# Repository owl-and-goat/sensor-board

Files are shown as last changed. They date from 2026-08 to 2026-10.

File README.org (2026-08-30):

#+title: sensor board

* stackup & antenna
see https://jlcpcb.com/impedance; stackup is currently set to 1.6 mm, controlled
impedance, 1 oz copper on all layers, which gives 0.203 mm / 0.008" outer
prepreg thickness for the "no requirement" stackup. board thickness is 1.6 mm ≈
0.062", so we'll be using the first of [[https://www.silabs.com/documents/public/application-notes/an1088-designing-with-pcb-antenna.pdf][these]] reference layouts.

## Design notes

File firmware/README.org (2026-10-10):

#+title: firmware

* build and flash

a board needs two images: the bootloader from =../bootloader=, at the start
of flash, and this firmware after it. the bootloader only swaps in a firmware
update (see below) and starts the firmware. from the top of the repository:

#+begin_src sh
  just flash                  # both, through the st-link on the jtag port
  just update                 # the firmware, over usb, through the running firmware
  just update-all             # the same for every attached board, one after the other
  just push                   # the firmware, to every board on the network, through the attached one
  just dfu-flash              # both, over usb, through the rom bootloader
  just dfu-flash-all          # the same for every attached board, one after the other
#+end_src

with several boards attached, =just update=, =just push= and =just dfu-flash=
take =--board <serial>=. to flash only the firmware through the probe and
watch the board's log (the bootloader has to be on the board already):

#+begin_src sh
  cargo run --release         # flash, reset, stay attached (ctrl-c to leave)
#+end_src

** firmware updates

=just update= runs =sensor-board-cli firmware update <image>= with the image
that =just firmware-image= builds. the board writes the image to its staging
area in flash, verifies it, and restarts. its bootloader then swaps the two
firmwares, which takes about ten seconds. the new firmware first runs on
trial. once the board is back on its network (or has no network to join),
the update is confirmed. if the board restarts before that, or is not back
within five minutes, the bootloader restores the old firmware. =firmware
status= shows which build is running and the state of the update.

=just push= runs =firmware push <image>=, which updates every board on the
network without plugging any of them in. the attached board receives the
image over usb and offers it to the others every ten seconds. a board that
runs another build fetches the image from the attached board in small
chunks, verifies it, and restarts into it in the same way, including the
trial. the command follows the boards' reports, which show the build each
board runs. it updates the attached board last, once every board it has
heard from runs the image. a board whose trial of a build failed does not
fetch that build again.

during a push, the command shows a summary line with the number of boards
that run the image, and below it a progress bar for each board that is
fetching. the bars are based on the chunks that the boards request from the
attached board:

#+begin_example
  ⠙ 1 of 3 other boards run build 1791154812 (2m)
  4B0041000350475532303120 ███████████████░░░░░░░░░░░░░  56%    1.85 KiB/s  eta 48s
  a board                  ███░░░░░░░░░░░░░░░░░░░░░░░░░  12%    1.71 KiB/s  eta  2m
  4D0021000350475532303120 ████████████████████████████ 100%  restarting
#+end_example

a bar shows the board's serial number once the board has sent its id.
firmware from before 2026-10-04 does not send it, so such a board is shown
as "a board". a board that has the whole image keeps its bar for half a
minute while it verifies the image, restarts and swaps, and is listed as
=updated= at its next report. the bars are only drawn on a terminal (and not
if =TERM= is =dumb=), and only if the attached board's firmware can report
progress (run =just update= first if it cannot).

all boards fetch at the same time, even when they relay for each other (see
=TODO.org=). a board can only be updated this way once it runs a firmware
that supports it, so its first such firmware has to come over usb.

a board stays on its network through all of this: its stored configuration
is in a separate page that neither firmware slot covers.

** without the firmware: usb dfu

=just dfu-flash= asks the running firmware to enter the rom bootloader and
then runs the command below. the command also works on a board that entered
the rom bootloader another way (see "getting into the bootloader"). with
several boards in the rom bootloader, select one with =dfu-util -p <usb
path>= (=lsusb -t= shows the paths).

#+begin_src sh
  dfu-util -d 0483:df11 -a 0 -s 0x08000000:leave -D target/sensor-board-flash.bin
#+end_src

the image is the bootloader, padded with blank flash up to 0x08007000,
followed by the firmware (=just firmware-image=, then the bootloader's part
of =_flash-image= in the =Justfile=).

* talking to a board: sensor-board-cli

the firmware is a usb device with one vendor interface, which carries
[[https://github.com/jamesmunns/postcard-rpc][postcard-rpc]] messages. =../protocol= defines the endpoints and all their
types. the firmware serves them (=src/rpc.rs=) and =../cli= calls them. a
board's usb serial number is its chip's unique id, and =--board= takes any
unambiguous prefix of it.

#+begin_src sh
  cd ../cli
  cargo run -- list                        # every board: firmware build, network status
  cargo run -- network init                # put all attached boards on one thread network
  cargo run -- network dataset --board 4b  # that network's dataset, hex (holds the network key)
  cargo run -- network neighbors --board 4b  # that board's direct neighbors and their link quality
  cargo run -- network routers --board 4b  # every router, and the board's route to it
  cargo run -- network leave --board 4d
  cargo run -- coprocessor status --board 4d           # what cpu2 has installed and is running
  cargo run -- coprocessor install <image> --board 4d  # see "a new board" below
  cargo run -- coprocessor uninstall --board 4d        # remove the wireless stack
  cargo run -- bootloader --board 4d       # reboot into the rom bootloader
  cargo run -- firmware status --board 4d  # the running build, and the state of an update
  cargo run -- firmware update <image> --board 4d  # see "firmware updates" above
  cargo run -- firmware push <image> --board 4d    # update every board on the network
  cargo run -- network addresses --board 4b  # that board's ipv6 addresses
  cargo run -- network show                # every sensor board on the network; see below
  cargo run -- reports watch               # print the boards' sensor reports as they arrive
  cargo run -- metrics show --board 4d     # the board's current prometheus metrics
  cargo run -- config show --board 4d      # the board's configuration
  cargo run -- config set --board 4d --sensor temperature=30s  # see "board configuration" below
#+end_src

=network init= puts every attached board on one network. the boards join one
at a time, and the command waits for each to attach. it chooses the network
in this order: the one saved by an earlier run, in
=~/.local/state/sensor-board/dataset= (=--dataset-path= selects another
file); if nothing is saved, the network of the first board that has one;
otherwise a new network (random key, pan id and channel). the chosen network
is saved, so that a board plugged in on its own later joins the same one.
=--force-reinit= always creates a new network and moves the attached boards
to it. the saved file contains the network key.

the host creates the dataset, and a board is only ever told to join one. a
board keeps its dataset in flash and rejoins at every power-up, until
=network leave=.

** the boards on a network

=network show= lists the sensor boards on a thread network: serial number,
rloc16, ipv6 address, and the link to each board.

#+begin_src sh
  cargo run -- network show                    # through an attached board, or else the border router
  cargo run -- network show --board 4c         # through that attached board
  cargo run -- network show --border-router    # through the border router at cerberus:8081
  cargo run -- network show --border-router otbr.lan:8081
#+end_src

through an attached board, that board multicasts a discovery request, and
every board that receives it replies with its serial number, rloc16 and
addresses. through a border router, the cli reads the list of devices from
the border router's rest api and sends the request to each device's routable
address itself, from udp port 61623. this machine needs a route to the thread
network for that.

- a board is listed only if its firmware has discovery. boards on an older
  firmware and other thread devices do not reply.
- the address is the board's routable address if it has one, and its
  mesh-local address otherwise.
- age, quality and avg rssi describe the link between each board and the
  device that was asked: the attached board, or the border router. they show
  as =-= for a board that has no direct radio link with that device, and for
  the attached board itself. the attached board's parent also shows =-=
  while the attached board is a child, as in =network neighbors=.
- the border router's api has no age or rssi, and it has the quality only for
  boards that are routers.

tested on 2026-10-10 with one board on a firmware that has discovery: through
that board, which lists itself, and through the border router, with the
quality once the board was a router. not tested: a second board's reply
arriving through the attached board, and the link columns filled from the
attached board's neighbor table.

** sensor reports

every board multicasts a report with its sensor readings to its network
every ten seconds. =reports watch= prints the reports that one attached
board receives, including that board's own, for as long as the command runs.
the board has to stay attached: if it goes away (unplugged, reflashed), the
command waits for it to come back. any board can do this. a board only
understands reports from firmware with the same report layout, and ignores
the rest. =firmware push= also uses these reports, to learn which build each
board runs.

** metrics

a board exports its metrics to prometheus itself, over its thread network
and a border router. how it exports them depends on the power mode in its
configuration (see below):

- =aux=: the board serves a scrape endpoint at =/metrics= on tcp port 9469.
  it handles one scrape at a time.
- =battery=: the board pushes to the pushgateway in its configuration after
  every sensor read, as job =sensor_board= with its serial number as the
  instance. after a failed push it waits a minute before the next one.

a board without a configuration does neither.

the metrics are the readings of the sensors enabled in the configuration,
each read at its own interval, plus counters for scrapes and pushes. every
metric has a =board= label with the board's serial number. =metrics show=
prints the current metrics over usb.

to scrape a board, prometheus needs an address that is reachable from
outside the thread network. =network addresses= lists it as =routable=. a
board gets one once a border router advertises a prefix.

#+begin_src yaml
  scrape_configs:
    - job_name: sensor-board
      static_configs:
        - targets: ["[fd12:3456:789a:1:4c51:2d3d:c69c:4af6]:9469"]
#+end_src

a pushgateway is set as an ipv6 address and a port. the border router has to
be able to route from the board to that address:

#+begin_src sh
  cargo run -- config set --power-mode battery --pushgateway '[fd12:3456::1]:9091'
#+end_src

tested on a board on 2026-10-10: metrics over usb, switching between the two
modes when the configuration changes, pushes to addresses where nothing
answers, and a scrape with =curl= from a machine on the lan, through a
border router. not tested yet: a push that succeeds.

** board configuration

a board stores a configuration in flash, next to its network's dataset. it
holds the board's number, its power mode, and for each sensor either a poll
interval or that the sensor is off. =config show= prints it. =config set=
changes the settings it is given and keeps the rest. the power mode also
selects how the board exports its metrics (see "metrics" above):

#+begin_src sh
  cargo run -- config set --id 3 --power-mode aux    # a board's first configuration needs these two
  cargo run -- config set --sensor temperature=30s --sensor color=off
  cargo run -- config show
#+end_src

with =--remote <serial>=, both commands apply to a board that is not
attached. the attached board asks it over their network, and gives up after
six seconds. =--remote= takes the board's full serial number, as =reports
watch= prints it.

#+begin_src sh
  cargo run -- config set --remote 4D0021000350475532303120 --sensor temperature=30s
#+end_src

a firmware that changes the layout of the configuration (by adding a sensor,
for example) cannot read a configuration that the previous firmware stored.
the board then has no configuration until it is set again. two boards whose
firmwares have different layouts do not answer each other's requests either.

so far only the metrics use the configuration: the power mode, the
pushgateway, and the intervals of the sensors that have a driver. the
board's number is not used yet. sensor reports are sent every ten seconds
regardless, and a board on battery is still a full router.

* getting into the bootloader

only needed for dfu; probe-rs does not need it. any of these puts the chip in
usb dfu mode (=lsusb= shows =0483:df11=):

- short the two pads of jp1 (boot0) while plugging in usb. this is hardware
  only, so it works whatever is in flash. take the coin cell out first: vbus
  and the cell share a net.
- =sensor-board-cli bootloader=, while the firmware is running.
- three boots in a row that end in a panic, a hard fault or a watchdog reset.
  a single failure only restarts the firmware.

* cpu2: fus, the thread stack, and openthread

cpu2 (the cortex-m0+ radio core) runs st's signed firmware: fus (the
firmware upgrade service) and, once installed, the thread ftd stack.

** a new board

a new chip is blank, with an old fus and no wireless stack. from the top of
the repository, with only the new board on usb:

#+begin_src sh
  just new-board          # bootloader and firmware over dfu, then fus and the thread stack; under a minute
  just cli network init   # join the network saved by an earlier run
#+end_src

=just new-board= fetches st's two images, verifies them against known hashes,
and then runs these commands:

#+begin_src sh
  dfu-util -d 0483:df11 -a 0 -s 0x08000000:leave -D sensor-board-flash.bin
  sensor-board-cli coprocessor install stm32wb5x_FUS_fw.bin          # fus 1.2.0 -> 2.2.0, a few seconds
  sensor-board-cli coprocessor install stm32wb5x_Thread_FTD_fw.bin   # about half a minute
#+end_src

without =--board=, =coprocessor install= selects the only attached board
whose coprocessor is running fus, which is the new one. it reads the kind
and version from the image, and skips a board that already has that version.

fus can only install while fus itself is running, so a board that has a
stack needs =coprocessor uninstall= first.

the third and fourth boards were set up this way on 2026-10-04. the first
two got their stacks in september from the text console of the bring-up
firmware (commit 9caa670).

** result (2026-09-16, two boards side by side on one hub)

a leader (rloc16 0xd400) and b child (0xd401) on channel 14, pan 0x5f11.
ping a to b 5/5 with 21 to 69 ms rtt, b to a 5/5 with 21 to 23 ms. a's
neighbor table: b at rssi -18 dbm, link margin 82 db, lqi 3. antenna,
balun and stack all work; range and tx power are untested.

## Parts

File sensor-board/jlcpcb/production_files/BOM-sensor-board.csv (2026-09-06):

Comment | Designator | Footprint | LCSC | Quantity
0.1uF | C12,C15,C16,C17,C18,C2,C21,C22,C23,C30,C31,C4,C6,C7,C9 | C_0402_1005Metric | C141382 | 15
100K | R17 | R_0402_1005Metric | C25741 | 1
100pF | C10 | C_0402_1005Metric | C1546 | 1
10k | R2,R3,R6,R7,R8,R9 | R_0402_1005Metric | C25744 | 6
10nH | L1 | L_0402_1005Metric | C3911026 | 1
10uH | L2 | L_0805_2012Metric | C162582 | 1
18 uH | L3,L4,L5,L6 | L_0603_1608Metric | C275349 | 4
1M | R13,R14 | R_0402_1005Metric | C26083 | 2
1N4148WS | D2 | D_SOD-323 | C2128 | 1
1k | R1,R10,R11,R12,R15,R16,R19,R20,R21 | R_0402_1005Metric | C11702 | 9
1uF | C24,C32,C8 | C_0402_1005Metric | C52923 | 3
2.2M | R18 | R_0603_1608Metric | C22938 | 1
32.768KHz | Y2 | Crystal_SMD_3215-2Pin_3.2x1.5mm | C94673 | 1
32MHz | Y1 | Crystal_SMD_2016-4Pin_2.0x1.6mm | C5441424 | 1
33 pF | C25,C26,C27,C28 | C_0402_1005Metric | C1562 | 4
4.7uF | C11 | C_0805_2012Metric | C1779 | 1
4.7uF | C1,C13,C14,C19,C20,C29 | C_0402_1005Metric | C23733 | 6
5.1k | R4,R5 | R_0402_1005Metric | C25905 | 2
6.2pF | C3,C5 | C_0402_1005Metric | C82154 | 2
LED | D1 | LED_0805_2012Metric | C84256 | 1
MCP1703Ax-300xxTT | U3 | SOT-23 | C625372 | 1
MLPF-WB55-01E3 | U1 | MLPF-WB55-01E3_STM | C2651048 | 1
STM32WB55CCUx | U2 | QFN-48-1EP_7x7mm_P0.5mm_EP5.6x5.6mm | C404023 | 1
SW_Push | SW1 | SW_SPST_TS-1088-xR020 | C720477 | 1
Si2312 | Q1,Q2 | SOT-23 | C142518 | 2
USB_C_Receptacle_USB2.0_16P | J1 | USB_C_Receptacle_G-Switch_GT-USB-7010ASV | C2988369 | 1

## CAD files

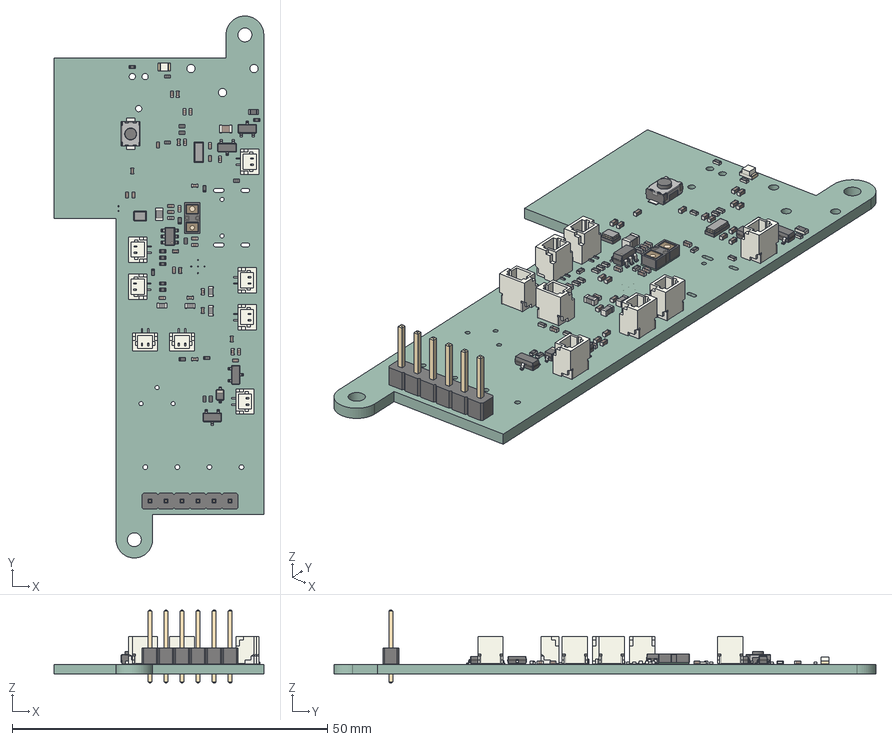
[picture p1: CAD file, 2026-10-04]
sensor-board/sensor-board.step
33.2 x 85.9 x 11.5 mm
C_0402_1005Metric x 31
D_SOD-323
R_0402_1005Metric x 20
SOT-23 x 4
Crystal_SMD_3215-2Pin_3.2x1.5mm
SOT-23-6
JST_SH_BM02B-SRSS-TB_1x02-1MP_P1.00mm_Vertical x 8
L_0805_2012Metric
L_0603_1608Metric x 4
Crystal_SMD_2016-4Pin_2.0x1.6mm
LED_0805_2012Metric
ST_VL53L1x
C_0805_2012Metric
PinHeader_1x06_P254mm_Vertical
R_0603_1608Metric
L_0402_1005Metric
SW_SPST_TS-1088-xR020
sensor-board_PCB

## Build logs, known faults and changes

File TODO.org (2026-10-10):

#+title: sensor board todo
#+todo: TODO(t) | DONE(d) WONTFIX(w)

* Layout fixes
** Grounding (fix before fab)                                                                                            :ground:
*** DONE [#A] Add a via array to the MCU (U2) exposed pad
CLOSED: [2026-09-02 Wed 22:45]
Pin 49 is VSS and the RF ground return. It currently reaches ground through
a single 0.4 mm F.Cu trace from the pad centre (174.49, 54.49) to the via at
pin 22. Put 9-16 GND vias in the pad at 0.8-1.0 mm pitch.
*** DONE [#A] Add GND vias at the balun/filter (U1) ground pads A2, B1, B2, B3
CLOSED: [2026-09-03 Thu 21:54]
Nearest GND via is 1.6-2.6 mm away (the pin-22 VSSRF via at 171.06, 56.24),
shared with the VDDRF decoupling. ~2 mm of trace is ~25 ohm at 2.4 GHz. One
via per pad, directly at or under the pad.
*** DONE [#A] Add GND vias at the VDDRF decoupling caps C9 and C10 ground pads
CLOSED: [2026-09-03 Thu 22:53]
Pads at (168.85, 56.90) and (169.87, 56.90); they currently return via the
same F.Cu GND trace to the pin-22 via.
*** DONE [#A] Give every GND pad its own via
CLOSED: [2026-09-03 Thu 22:11]
Only 8 of 81 SMD GND pads are within 1 mm of a GND via; 25 are >3 mm away;
158 mm of GND is routed as F.Cu traces. Worst cases:
- [X] U9 (FDC2114) GND pins 3, 4 and thermal pad 17: 3.9-4.3 mm
- [X] U5 (VL53L1X) GND pins 2, 3, 4, 6, 12: 2.4-4.1 mm
- [X] C17, C20 (VL53L1X decoupling): 3.8 / 4.3 mm
- [X] C15: 4.3 mm
- [X] U2 pin 32 VSSSMPS: 2.8 mm
- [X] C1, C14, C6 (SMPS caps): 2.0-2.6 mm
- [X] C12: 3.1 mm; C23: 2.5 mm
- [X] U11 (DRV5032) GND: 5.9 mm
- [X] MIC1 GND pads: 1.9-3.9 mm
- [X] U8 (LIS2DE12) GND pads: 3.2-3.7 mm
- [X] U6 (TLV4082) GND: 2.4 mm
- [X] J1 (USB-C) shell/GND pads: 5-7 mm
*** DONE [#A] Add GND pours on F.Cu and B.Cu with stitching vias
CLOSED: [2026-09-03 Thu 22:20]
Exclude the antenna area (everything left of x = 167.1 for y < 61.06). Keep a
generous clearance from the FDC2114 tank/electrode traces. Stitch to In1 at
<= 2 mm spacing in the RF section (AN5165).

** Signals routed on plane layers (fix before fab)                                                                       :planes:
*** WONTFIX [#A] Move VLXSMPS (SMPS switch node) off In1
CLOSED: [2026-09-03 Thu 22:22]
2.1 mm slot at x = 175.77, y 58.42-60.52, directly under C1 and C14. Re-place
L1 and/or C1/C14 so pin 33 -> L1 is a short, direct F.Cu trace.
*** WONTFIX [#A] Move SCL and SDA off In1
CLOSED: [2026-09-03 Thu 22:22]
Two ~6 mm diagonal slots under the MCU south-east quadrant:
scl (175.26, 54.84) -> (179.68, 59.26); sda (174.74, 55.87) -> (179.07, 60.20).
Crossed by usb_d+/usb_d-, sai1_d1, dist_int, dist_shut and the SMPS GND traces.
*** WONTFIX [#A] Move water1 and water2 off In2
CLOSED: [2026-09-03 Thu 22:23]
13 mm and 12 mm on the +3V0 plane; together they wall off a 3V0 island under
the MCU that is only fed through the F.Cu decoupling vias.
*** WONTFIX [#A] Move hp1 and hp3 off In2
CLOSED: [2026-09-03 Thu 22:23]
hp1 slot (168.0, 57.23) -> (170.3, 54.2) passes directly under the balun U1.
*** DONE [#B] Remove the stray GND track segments on In2 near (169.3-169.5, 57.8-59.05)
CLOSED: [2026-09-03 Thu 22:26]

** Crystals                                                                                                             :crystal:
*** DONE Local ground islands under Y1 and Y2 (AN2867 structure) - keep as is
CORRECTION to the first review pass, which wrongly said there was no copper
under the crystals. What is actually there: a filled GND =gr_rect= on In1
under each crystal, isolated from the main In1 plane by the keepout gap, a
GND guard ring of graphic lines on F.Cu, a via ring tying the top ring to the
island, and a single-point tie to the rest of ground:
- Y1: via (169.3, 59.05) -> In2 stub -> via (169.5, 58.47) -> main In1 plane
  and B.Cu track to the U2 pin 22 (VSSRF) via.
- Y2: via (178.9, 48.4) -> B.Cu track -> via (179.0, 47.5) -> main In1 plane.
Only crystal-related grounds (Y1.2, C3.2, C5.2) land on the islands. The
keepouts are what create the isolation gap; do not delete them.
*** DONE [#B] Connect Y1 pad 4 to the guard ring / island
CLOSED: [2026-09-03 Thu 22:28]
Pad 4 (171.6, 61.25) has no net; only one of the two case-ground pads is
grounded. Needs a schematic change.
*** WONTFIX [#B] Separate the LSE traces
CLOSED: [2026-09-03 Thu 22:30]
lf_osc+ and lf_osc- run side by side for 2.2 mm at 0.24 mm gap (y = 49.97 and
50.42, x 176.9-179.1), outside the ring. Put a GND trace between them or
spread them.
*** WONTFIX [#B] Move the +3V0 traces to C2/C7 away from the LSE traces
CLOSED: [2026-09-03 Thu 22:30]
+3V0 at (177.04-178.05, 49.47) and (177.24-178.31, 51.05) run 0.2 mm from the
LSE traces where they leave the ring.
*** DONE [#C] Relax the via ring pitch to a DRC-legal hole-to-hole spacing
CLOSED: [2026-09-03 Thu 22:30]
Currently 0.38 mm; this is the source of most hole_to_hole warnings. 0.6-1.0
mm pitch loses nothing for a guard ring.
*** DONE [#C] Consider landing the Y2 island tie at an MCU VSS pin
CLOSED: [2026-09-03 Thu 22:33]
AN2867 wants the local ground tied to the nearest MCU ground pin; the Y2 tie
currently lands on the main plane at (179.0, 47.5). Y1's tie already reaches
pin 22. Low priority once the U2 exposed pad has its via array.
*** WONTFIX [#C] Move C3/C5 (LSE load caps) between the crystal and the MCU
CLOSED: [2026-09-03 Thu 22:33]
They are on the far side of Y2 at x = 182.0, inside the ring. Optional;
would need the ring reshaped.
*** Note: no In2 (+3V0) copper under either island
Y2 by the 4-layer keepout, Y1 because the ring via antipads island the In2
fill and it is removed. Harmless for the crystals (the In1 island shields
them); it just leaves a ~4x4 mm hole in the 3V0 plane. No action.

** Antenna / RF                                                                                                              :rf:
*** DONE [#B] Reroute color_int away from the antenna base
CLOSED: [2026-09-03 Thu 22:33]
F.Cu at x = 168.06 from y 56.56 to 60.50, between the feed pad and the
shorting-arm pads; its via at (168.2, 56.5) is 0.45 mm below the 50 ohm feed.
Take it up on B.Cu from U2 pin 19 instead.
*** DONE [#B] Make In2 GND (not +3V0) in the antenna base / RF section
CLOSED: [2026-09-03 Thu 22:36]
AN1088 wants ground on layers 2 and 4 next to the antenna. Cut the 3V0 plane
back from the antenna base and RF section, fill with GND, stitch to In1.
*** DONE [#C] Check the coin cell (BT1) body clearance from the antenna arm
CLOSED: [2026-09-03 Thu 22:37]
Holder pads at (183.98, 37.34) near the top edge; the arm runs x ~ 158.7,
y 40.7-60.6. Any large metal within ~5-10 mm of the arm will detune it.
*** WONTFIX [#C] Convert the antenna radiator polygon into pad 2
CLOSED: [2026-09-03 Thu 22:37]
Still a netless F.Cu graphic; produces the shorting_items DRC error against
pad 2 (GND). Fine as fabricated, but the pad form removes the error.
*** DONE 50 ohm feed: 0.37 mm on 0.203 mm prepreg computes to ~51 ohm; OK
*** DONE Shorting arm has two THT GND pads at the base; OK
*** DONE No copper on any layer under the antenna; plane edge at the base; OK

** SMPS                                                                                                                    :smps:
*** WONTFIX [#B] Tighten the SMPS loop after moving VLX back to F.Cu
CLOSED: [2026-09-03 Thu 22:37]
L2 is 3 mm from Y1. Keep VLX short, keep C1/C14 GND on their own vias, give
pin 32 (VSSSMPS) its own via.

** Sensor and analog nets                                                                                                :sensor:
*** DONE [#B] Separate the FDC2114 channel 3 B trace from the channel 2 electrode net
CLOSED: [2026-09-03 Thu 22:50]
IN3B runs ~10 mm on B.Cu at the 0.1 mm minimum gap from Net-(J10-Pin_1)
(channel 2 electrode). Channel-to-channel crosstalk on the most sensitive node.
*** DONE [#B] Separate the channel 3 electrode net from SCL
CLOSED: [2026-09-03 Thu 22:50]
Net-(J11-Pin_1) runs 1.9 mm at 0.1 mm gap from scl on B.Cu.
*** DONE [#B] Bundle each FDC channel's A/B pair together, away from other channels and I2C
CLOSED: [2026-09-03 Thu 22:51]
*** DONE [#C] Shorten / match the FDC sensor trace lengths
CLOSED: [2026-09-03 Thu 22:51]
Per-channel totals: ch0 ~16 mm, ch1 ~18 mm, ch2 ~23 mm, ch3 ~33 mm. TI:
short traces, matched if matched channel response is needed.
*** WONTFIX [#B] Move the relay GPIO trace away from the comparator input U6 IN2
CLOSED: [2026-09-03 Thu 22:52]
relay on B.Cu runs at x = 173.18 and x = 173.78 on both sides of the 1 Mohm
U6-IN2 node at x = 173.48 (y 65-67.7), 0.3 mm pitch; hp4 also runs 3.5 mm
alongside it on F.Cu. Relay edges will fire false water events.
*** WONTFIX [#C] Reroute motion (B.Cu, x = 175.25) so it does not run over the water2 slot
CLOSED: [2026-09-03 Thu 22:52]
Moot once water2 leaves In2.

** Board / DRC housekeeping                                                                                                 :drc:
*** DONE [#A] Close the board outline
CLOSED: [2026-09-03 Thu 22:37]
Top-right corner: top edge ends at (190.50, 35.66), right edge starts at
(190.53, 35.69). JLCPCB will query an open outline.
*** DONE [#C] Fix the vendor footprint courtyards (U1, MIC1, U8) so DRC is readable
CLOSED: [2026-09-03 Thu 22:37]
*** DONE [#C] Clean up the co-located / too-close vias flagged by hole_to_hole
CLOSED: [2026-09-03 Thu 22:37]
Mostly the Y1 ring; also water1/water2, hp2/hp3, sda/scl, JP1 pairs.

* Firmware
** TODO Update boards over the mesh in an order that keeps the network together
=firmware push= makes every board fetch the update at once, as soon as it
receives the offer. A board is off the network for about half a minute, while
its bootloader swaps the images and until it has rejoined. A router that is
off the network does not relay, so a board behind it loses its connection to
the board it was fetching from, and has to wait for the next offer to
continue. Instead, update the leaf boards first (those that no other board
is reached through), then work inwards to the board on USB, which is updated
last. Update one board at a time, and wait for each to report its new build
before starting the next.

With five boards, every board is a router, so leaves cannot be identified by
role. The order has to come from the gateway's router table (=network
routers=): update the board with the highest path cost first, and never
update a board that is the next hop to a board that is still waiting.
* Rev. 2
** TODO fix the pin numbering for the color sensor footprint
half of them are the wrong way gdi

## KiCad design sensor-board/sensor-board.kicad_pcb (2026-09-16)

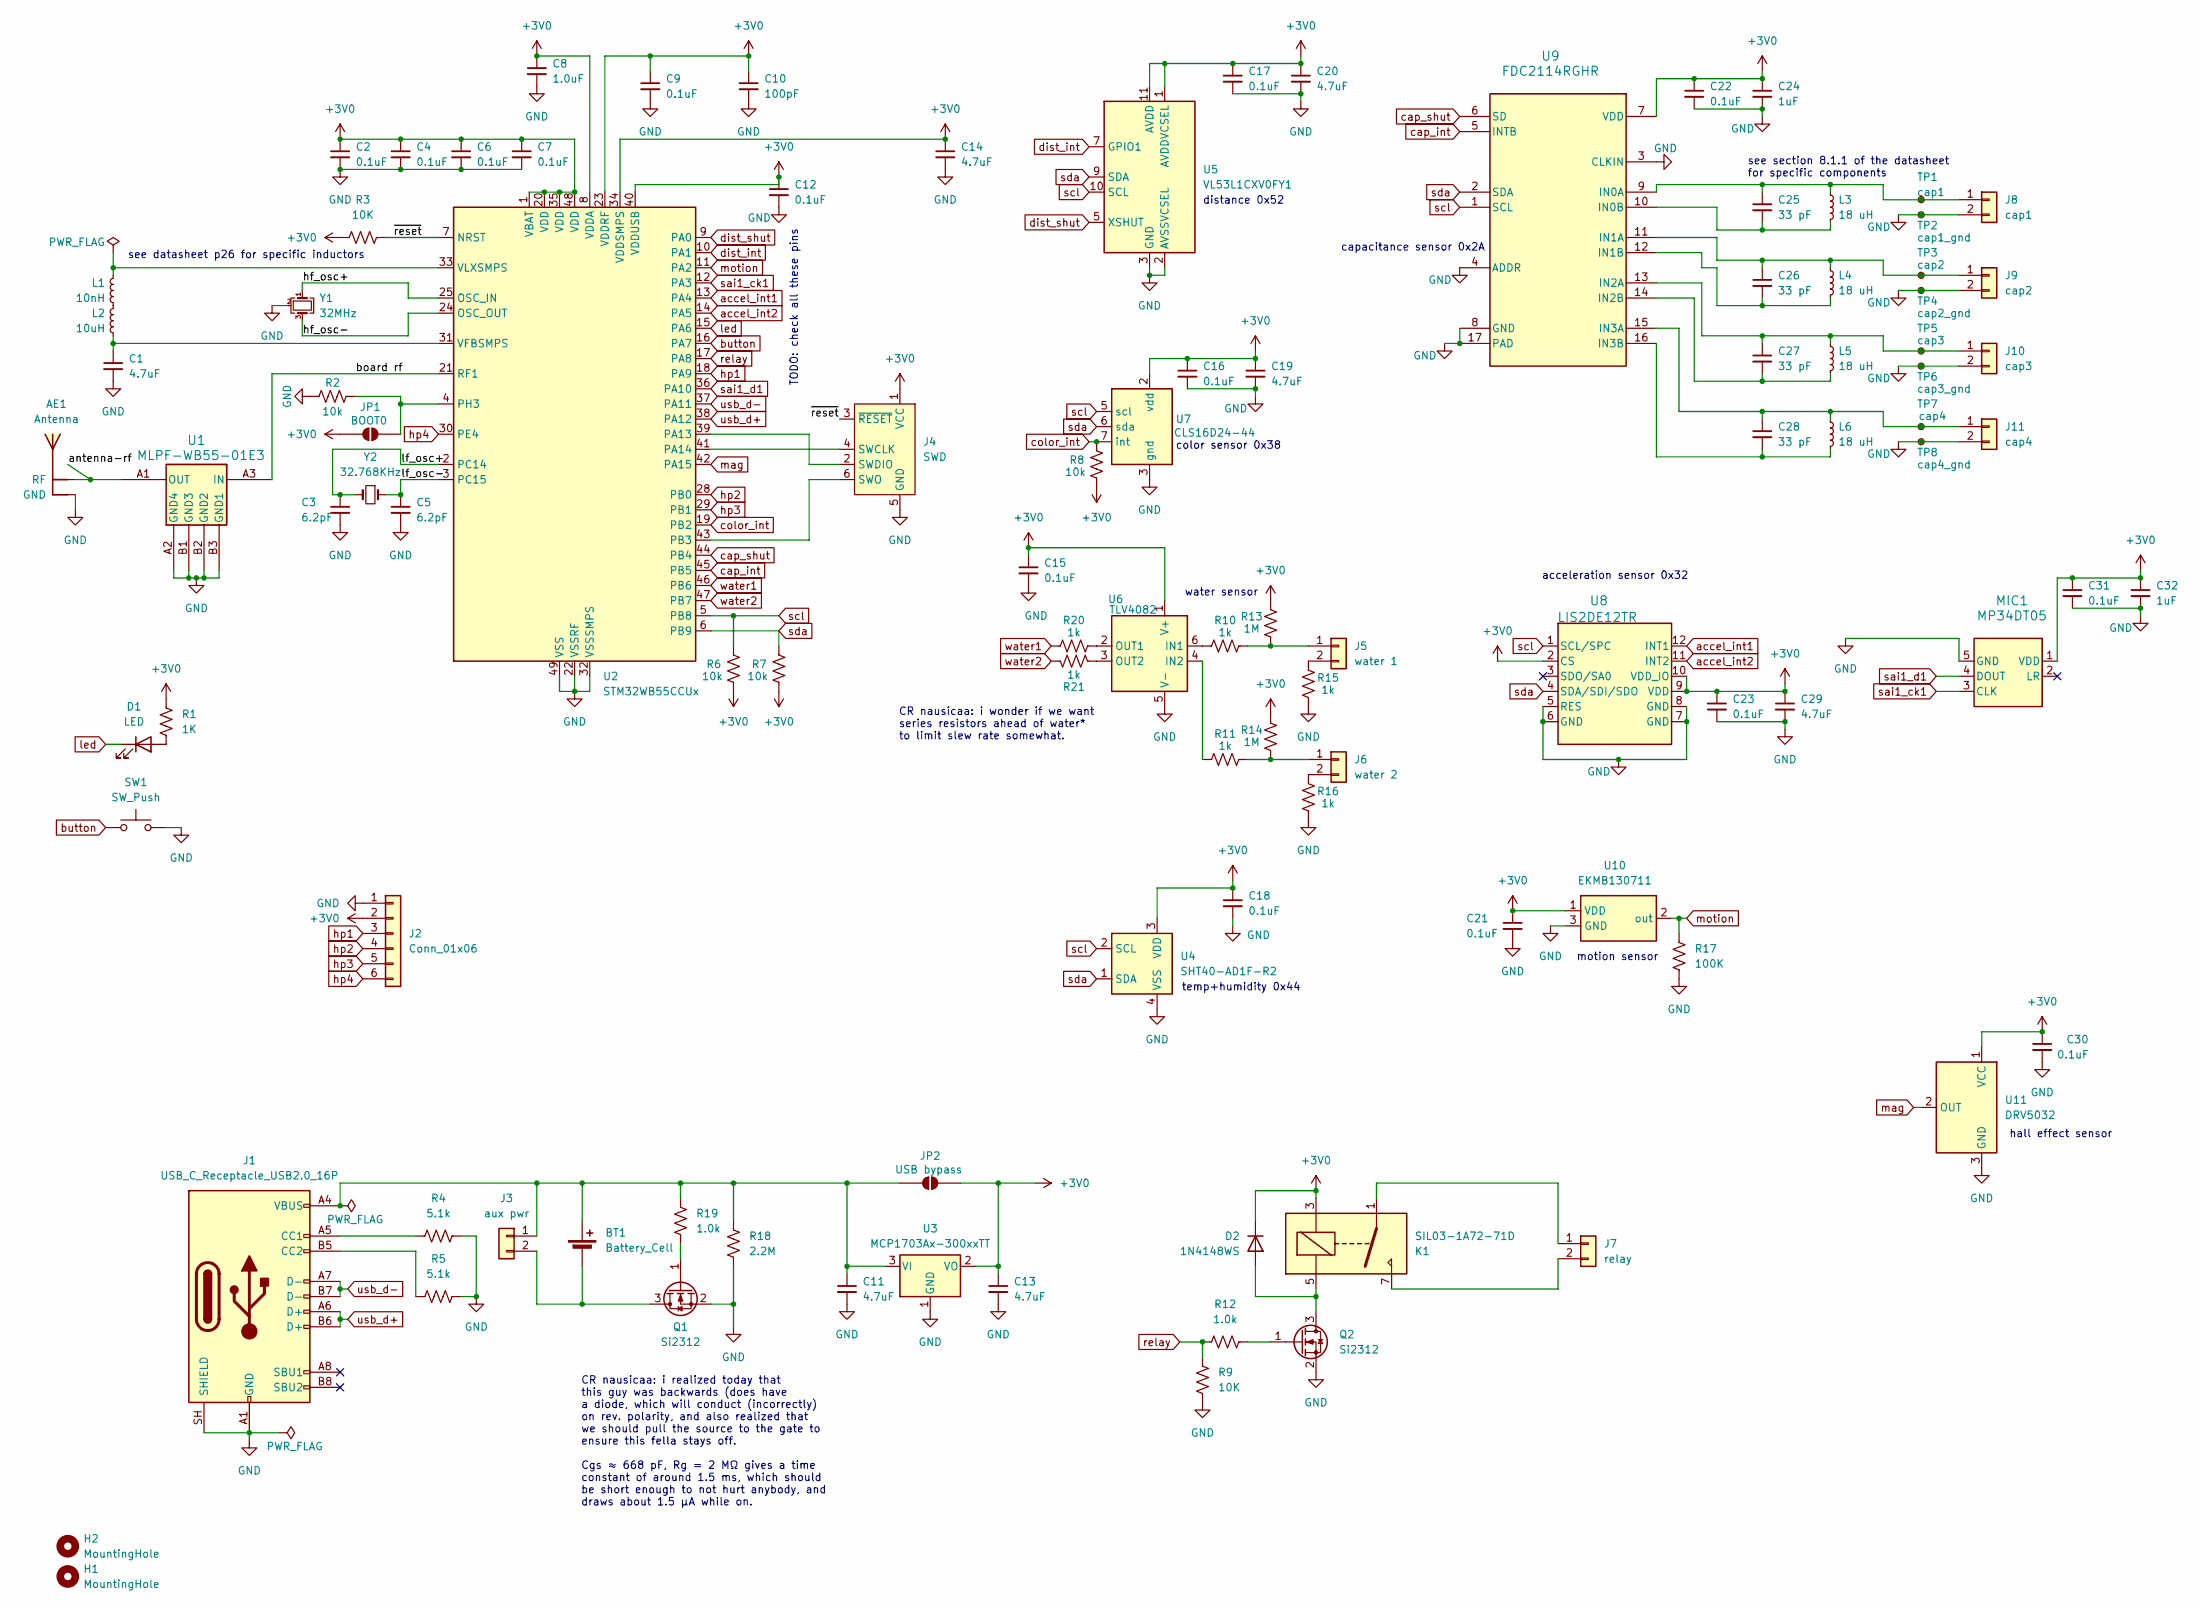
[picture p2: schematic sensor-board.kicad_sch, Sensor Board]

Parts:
AE1: Antenna; Antenna_2.4GHz_InvertedF_SiLabs
BT1: Battery_Cell; BatteryHolder_CR2032
C1, C13, C14, C19, C20, C29: 4.7uF; C_0402_1005Metric; LCSC C23733
C2, C4, C6, C7, C9, C12, C15, C16, C17, C18, C21, C22, C23, C30, C31: 0.1uF; C_0402_1005Metric; LCSC C141382
C3, C5: 6.2pF; C_0402_1005Metric
C8: 1.0uF; C_0402_1005Metric; LCSC C52923
C10: 100pF; C_0402_1005Metric; LCSC C1546
C11: 4.7uF; C_0805_2012Metric; LCSC C23733
C24, C32: 1uF; C_0402_1005Metric; LCSC C52923
C25, C26, C27, C28: 33 pF; C_0402_1005Metric; LCSC C1562
D1: LED; LED_0805_2012Metric; LCSC C84256
D2: 1N4148WS; D_SOD-323; LCSC C2128
H1, H2: MountingHole; MountingHole_2.2mm_M2
J1: USB_C_Receptacle_USB2.0_16P; USB_C_Receptacle_G-Switch_GT-USB-7010ASV
J2: Conn_01x06; PinHeader_1x06_P2.54mm_Vertical
J3: aux pwr; JST_SH_BM02B-SRSS-TB_1x02-1MP_P1.00mm_Vertical
J4: SWD; Tag-Connect_TC2030-IDC-NL_2x03_P1.27mm_Vertical
J5: water 1; JST_SH_BM02B-SRSS-TB_1x02-1MP_P1.00mm_Vertical
J6: water 2; JST_SH_BM02B-SRSS-TB_1x02-1MP_P1.00mm_Vertical
J7: relay; JST_SH_BM02B-SRSS-TB_1x02-1MP_P1.00mm_Vertical
J8: cap1; JST_SH_BM02B-SRSS-TB_1x02-1MP_P1.00mm_Vertical
J9: cap2; JST_SH_BM02B-SRSS-TB_1x02-1MP_P1.00mm_Vertical
J10: cap3; JST_SH_BM02B-SRSS-TB_1x02-1MP_P1.00mm_Vertical
J11: cap4; JST_SH_BM02B-SRSS-TB_1x02-1MP_P1.00mm_Vertical
JP1: BOOT0; SolderJumper-2_P1.3mm_Open_RoundedPad1.0x1.5mm
JP2: USB bypass; SolderJumper-2_P1.3mm_Open_RoundedPad1.0x1.5mm
K1: SIL03-1A72-71D; SIL031A7271D
L1: 10nH; L_0402_1005Metric
L2: 10uH; L_0805_2012Metric
L3, L4, L5, L6: 18 uH; L_0603_1608Metric
MIC1: MP34DT05; HCLGA4_MP34_STM
Q1, Q2: Si2312; SOT-23
R1: 1K; R_0402_1005Metric; LCSC C11702
R2, R6, R7, R8: 10k; R_0402_1005Metric; LCSC C25744
R3, R9: 10K; R_0402_1005Metric; LCSC C25744
R4, R5: 5.1k; R_0402_1005Metric; LCSC C25905
R10, R11, R15, R16, R20, R21: 1k; R_0402_1005Metric; LCSC C11702
R12, R19: 1.0k; R_0402_1005Metric; LCSC C11702
R13, R14: 1M; R_0402_1005Metric; LCSC C26083
R17: 100K; R_0402_1005Metric; LCSC C25741
R18: 2.2M; R_0603_1608Metric; LCSC C22938
SW1: SW_Push; SW_SPST_TS-1088-xR020; LCSC C720477
TP1: cap1; TestPoint_Pad_1.0x1.0mm
TP2: cap1_gnd; TestPoint_Pad_1.0x1.0mm
TP3: cap2; TestPoint_Pad_1.0x1.0mm
TP4: cap2_gnd; TestPoint_Pad_1.0x1.0mm
TP5: cap3; TestPoint_Pad_1.0x1.0mm
TP6: cap3_gnd; TestPoint_Pad_1.0x1.0mm
TP7: cap4; TestPoint_Pad_1.0x1.0mm
TP8: cap4_gnd; TestPoint_Pad_1.0x1.0mm
U1: MLPF-WB55-01E3; MLPF-WB55-01E3_STM; LCSC C2651048
U2: STM32WB55CCUx; QFN-48-1EP_7x7mm_P0.5mm_EP5.6x5.6mm; LCSC C404023
U3: MCP1703Ax-300xxTT; SOT-23; LCSC C625372
U4: SHT40-AD1F-R2; Sensirion_DFN-4_1.5x1.5mm_P0.8mm_SHT4x_NoCentralPad
U5: VL53L1CXV0FY1; ST_VL53L1x
U6: TLV4082; SOT-23-6
U7: CLS16D24-44; CLS-16D24-44-DF8TR8
U8: LIS2DE12TR; LGA-12_STM
U9: FDC2114RGHR
U10: EKMB130711; EKMB1307111K
U11: DRV5032; SOT-23
Y1: 32MHz; Crystal_SMD_2016-4Pin_2.0x1.6mm
Y2: 32.768KHz; Crystal_SMD_3215-2Pin_3.2x1.5mm

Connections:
+3V0: C2.1, C4.1, C6.1, C7.1, C8.1, C9.1, C10.1, C12.1, C13.1, C14.1, C15.1, C16.1, C17.1, C18.1, C19.1, C20.1, C21.1, C22.1, C23.1, C24.1, C29.1, C30.1, C31.1, C32.1, D2.1 (K), J2.2, J4.1 (VCC), JP1.1 (A), JP2.2 (B), K1.3, MIC1.1 (VDD), R1.1, R3.1, R6.1, R7.1, R8.1, R13.2, R14.2, U2.1 (VBAT), U2.8 (VDDA), U2.20 (VDD), U2.23 (VDDRF), U2.34 (VDDSMPS), U2.35 (VDD), U2.40 (VDDUSB), U2.48 (VDD), U3.2 (VO), U4.3 (VDD), U5.1 (AVDDVCSEL), U5.11 (AVDD), U6.1 (V+), U7.2 (vdd), U8.2 (CS), U8.9 (VDD), U8.10 (VDD_IO), U9.7 (VDD), U10.1 (VDD), U11.1 (VCC)
/antenna-rf: AE1.1 (RF), U1.A1 (OUT)
/board rf: U1.A3 (IN), U2.21 (RF1)
/hf_osc+: U2.25 (OSC_IN), Y1.1
/hf_osc-: U2.24 (OSC_OUT), Y1.3
/lf_osc+: C3.1, U2.2 (PC14), Y2.2
/lf_osc-: C5.1, U2.3 (PC15), Y2.1
/~reset: J4.3 (~RESET), R3.2, U2.7 (NRST)
GND: AE1.2 (GND), C1.2, C2.2, C3.2, C4.2, C5.2, C6.2, C7.2, C8.2, C9.2, C10.2, C11.2, C12.2, C13.2, C14.2, C15.2, C16.2, C17.2, C18.2, C19.2, C20.2, C21.2, C22.2, C23.2, C24.2, C29.2, C30.2, C31.2, C32.2, J1.A1 (GND), J1.A12 (GND), J1.B1 (GND), J1.B12 (GND), J1.SH (SHIELD), J2.1, J4.5 (GND), J8.2, J9.2, J10.2, J11.2, MIC1.5 (GND), Q1.2 (S), Q2.2 (S), R2.1, R4.2, R5.2, R9.1, R15.1, R16.1, R17.2, R18.2, SW1.2, TP2.1 (1_1), TP4.1 (1_1), TP6.1 (1_1), TP8.1 (1_1), U1.A2 (GND4), U1.B1 (GND3), U1.B2 (GND2), U1.B3 (GND1), U2.22 (VSSRF), U2.32 (VSSSMPS), U2.49 (VSS), U3.1 (GND), U4.4 (VSS), U5.2 (AVSSVCSEL), U5.3 (GND), U5.4 (GND), U5.6 (GND), U5.12 (GND), U6.5 (V-), U7.3 (gnd), U8.5 (RES), U8.6 (GND), U8.7 (GND), U8.8 (GND), U9.3 (CLKIN), U9.4 (ADDR), U9.8 (GND), U9.17 (PAD), U10.3 (GND), U11.3 (GND), Y1.2, Y1.4 (G)
unnamed: BT1.1 (+), C11.1, J1.A4 (VBUS), J1.A9 (VBUS), J1.B4 (VBUS), J1.B9 (VBUS), J3.1, JP2.1 (A), R18.1, R19.2, U3.3 (VI)
unnamed: BT1.2 (-), J3.2, Q1.3 (D)
unnamed: D1.2 (A), R1.2
unnamed: D2.2 (A), K1.5, Q2.3 (D)
unnamed: J1.A5 (CC1), R4.1
unnamed: J1.B5 (CC2), R5.1
unnamed: J4.4 (SWCLK), U2.41 (PA14)
unnamed: J4.2 (SWDIO), U2.39 (PA13)
unnamed: J4.6 (SWO), U2.43 (PB3)
unnamed: J5.1, R10.2, R13.1
unnamed: J5.2, R15.2
unnamed: J6.1, R11.2, R14.1
unnamed: J6.2, R16.2
unnamed: J7.1, K1.1
unnamed: J7.2, K1.7
unnamed: C25.1, J8.1, L3.1, TP1.1 (1_1), U9.9 (IN0A)
unnamed: C26.1, J9.1, L4.1, TP3.1 (1_1), U9.11 (IN1A)
unnamed: C27.1, J10.1, L5.1, TP5.1 (1_1), U9.13 (IN2A)
unnamed: C28.1, J11.1, L6.1, TP7.1 (1_1), U9.15 (IN3A)
unnamed: JP1.2 (B), R2.2, U2.4 (PH3)
unnamed: L1.2, L2.1
unnamed: Q1.1 (G), R19.1
unnamed: Q2.1 (G), R12.2
unnamed: C1.1, L2.2, U2.31 (VFBSMPS)
unnamed: L1.1, U2.33 (VLXSMPS)
unnamed: R10.1, U6.6 (IN1)
unnamed: R11.1, U6.4 (IN2)
unnamed: R20.2, U6.2 (OUT1)
unnamed: R21.2, U6.3 (OUT2)
unnamed: C25.2, L3.2, U9.10 (IN0B)
unnamed: C26.2, L4.2, U9.12 (IN1B)
unnamed: C27.2, L5.2, U9.14 (IN2B)
unnamed: C28.2, L6.2, U9.16 (IN3B)
accel_int1: U2.13 (PA4), U8.12 (INT1)
accel_int2: U2.14 (PA5), U8.11 (INT2)
button: SW1.1, U2.16 (PA7)
cap_int: U2.45 (PB5), U9.5 (INTB)
cap_shut: U2.44 (PB4), U9.6 (SD)
color_int: R8.2, U2.19 (PB2), U7.7 (int)
dist_int: U2.10 (PA1), U5.7 (GPIO1)
dist_shut: U2.9 (PA0), U5.5 (XSHUT)
hp1: J2.3, U2.18 (PA9)
hp2: J2.4, U2.28 (PB0)
hp3: J2.5, U2.29 (PB1)
hp4: J2.6, U2.30 (PE4)
led: D1.1 (K), U2.15 (PA6)
mag: U2.42 (PA15), U11.2 (OUT)
motion: R17.1, U2.11 (PA2), U10.2 (out)
relay: R9.2, R12.1, U2.17 (PA8)
sai1_ck1: MIC1.3 (CLK), U2.12 (PA3)
sai1_d1: MIC1.4 (DOUT), U2.36 (PA10)
scl: R6.2, U2.5 (PB8), U4.2 (SCL), U5.10 (SCL), U7.5 (scl), U8.1 (SCL/SPC), U9.1 (SCL)
sda: R7.2, U2.6 (PB9), U4.1 (SDA), U5.9 (SDA), U7.6 (sda), U8.4 (SDA/SDI/SDO), U9.2 (SDA)
usb_d+: J1.A6 (D+), J1.B6 (D+), U2.38 (PA12)
usb_d-: J1.A7 (D-), J1.B7 (D-), U2.37 (PA11)
water1: R20.1, U2.46 (PB6)
water2: R21.1, U2.47 (PB7)

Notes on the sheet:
temp+humidity 0x44
color sensor 0x38
motion sensor
acceleration sensor 0x32
CR nausicaa: i wonder if we want series resistors ahead of water* to limit slew rate somewhat.
see section 8.1.1 of the datasheet for specific components
hall effect sensor
water sensor
see datasheet p26 for specific inductors
TODO: check all these pins
CR nausicaa: i realized today that this guy was backwards (does have a diode, which will conduct (incorrectly) on rev. polarity, and also realized that we should pull the source to the gate to ensure this fella stays off. Cgs ≈ 668 pF, Rg = 2 MΩ gives a time constant of around 1.5 ms, which should 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
capacitance sensor 0x2A
distance 0x52

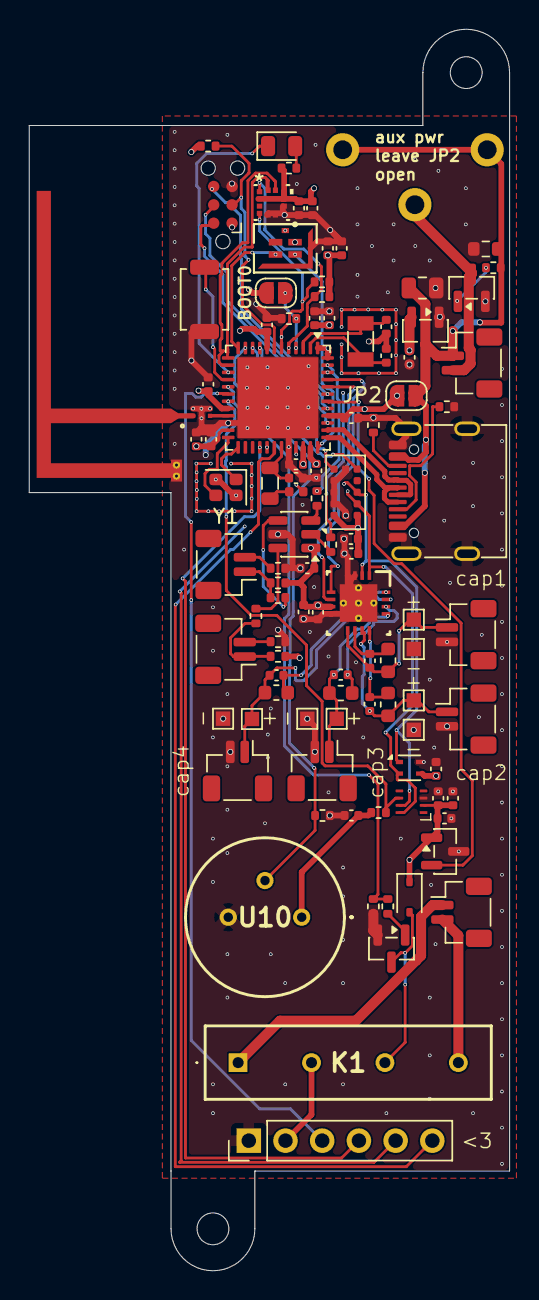
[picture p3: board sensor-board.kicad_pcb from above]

Board: 4 copper layers, 33.2 x 85.9 mm, 104 parts (0 on the bottom side), 66 nets.

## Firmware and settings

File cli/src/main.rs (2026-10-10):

//! Command-line client for sensor boards attached over USB.

mod board;
mod border_router;
mod config;
mod coprocessor;
mod discovery;
mod firmware;
mod network;
mod reports;

use std::path::PathBuf;

use anyhow::{Context, Result, bail};
use clap::{Args, Parser, Subcommand};

use board::Board;
use network::SavedDataset;
use protocol::{
    BoardId, HeaterDuration, HeaterPower, Link, NetworkStatus, Precision, Role, RouterId, Sensor,
    SensorValue, TempRh, TempRhReq,
};

#[derive(Parser)]
#[command(version, about = "Talk to sensor boards attached over USB")]
struct Cli {
    #[command(subcommand)]
    command: Command,
}

#[derive(Subcommand)]
enum Command {
    /// Show every attached board with its firmware and network status
    List,
    /// Manage the boards' Thread network
    #[command(subcommand)]
    Network(NetworkCommand),
    /// Manage the firmware of a board's radio coprocessor
    #[command(subcommand)]
    Coprocessor(CoprocessorCommand),
    /// Reboot a board into its ROM bootloader, to flash it over USB DFU
    Bootloader(Target),
    #[command(subcommand)]
    Sensor(SensorCommand),
    /// Receive the sensor reports that boards send over their network, through a board that
    /// stays attached
    #[command(subcommand)]
    Reports(ReportsCommand),
    /// Inspect a board's Prometheus metrics
    #[command(subcommand)]
    Metrics(MetricsCommand),
    /// Update a board's firmware without its ROM bootloader
    #[command(subcommand)]
    Firmware(FirmwareCommand),
    /// Show or change a board's configuration: which sensors it reads and how often, and how it is
    /// powered
    #[command(subcommand)]
    Config(ConfigCommand),
}

#[derive(Subcommand)]
enum ConfigCommand {
    /// Print a board's configuration
    Show(ConfigTarget),
    /// Change a board's configuration. Settings that are not given keep their values
    Set {
        #[command(flatten)]
        changes: config::Changes,

        #[command(flatten)]
        target: ConfigTarget,
    },
}

#[derive(Subcommand)]
enum FirmwareCommand {
    /// Show which firmware build a board runs, and its update status
    Status(Target),
    /// Send a board a firmware image and restart it into the image. The board rolls back to
    /// its previous firmware if the new one does not get it back on its network
    Update {
        /// The image, as built by `just firmware-image`
        image: PathBuf,

        #[command(flatten)]
        target: Target,
    },
    /// Update every board on the network. The attached board receives the image and offers
    /// it to the others, which fetch it over the network. The attached board is updated last
    Push {
        /// The image, as built by `just firmware-image`
        image: PathBuf,

        #[command(flatten)]
        target: Target,
    },
}

#[derive(Subcommand)]
enum ReportsCommand {
    /// Print the reports as they arrive
    Watch(Target),
}

#[derive(Subcommand)]
enum MetricsCommand {
    /// Print a board's current metrics, in the text format it serves to Prometheus or pushes to
    /// a Pushgateway
    Show(Target),
}

#[derive(Subcommand)]
enum NetworkCommand {
    /// Put every attached board on one network
    ///
    /// The first time this is run, this creates a new network. Every subsequent time, it puts
    /// boards on the same network. To override this behavior and create a new network, pass
    /// `--force-reinit`
    Init {
        /// Create a new network and move every attached board to it, regardless of the saved
        /// network and the networks the boards are on
        #[arg(long)]
        force_reinit: bool,

        /// The file the network's dataset is saved in. [default:
        /// $XDG_STATE_HOME/sensor-board/dataset]
        #[arg(long, value_name = "FILE")]
        dataset_path: Option<PathBuf>,
    },

    /// Leave the network and erase its dataset from the board
    Leave(Target),
    /// Print the dataset of a board's network. It contains the network key
    Dataset(Target),
    /// Print a board's neighbor table: its children, and the routers it has a direct radio link
    /// with, other than its parent
    Neighbors(Target),
    /// Print a board's router table: every router on its network, and whether the board reaches it
    /// directly or through another router
    Routers(Target),
    /// Print a board's IPv6 addresses. Prometheus needs a routable one to scrape the board
    Addresses(Target),
    /// List the sensor boards on the network: serial number, RLOC16, IPv6 address and link
    ///
    /// Asks through an attached board if there is one, and otherwise through the border router.
    /// Age, quality and RSSI describe the link between each board and the board or border
    /// router that was asked. They show as `-` for a board it has no direct radio link with, and
    /// a border router only reports the quality. A board whose firmware predates discovery is
    /// not listed
    Show {
        /// Ask through the border router whose REST API is at this address, or at cerberus:8081
        /// if no address is given
        #[arg(
            long,
            value_name = "HOST:PORT",
            num_args = 0..=1,
            default_missing_value = discovery::DEFAULT_BORDER_ROUTER,
            conflicts_with = "board"
        )]
        border_router: Option<String>,

        #[command(flatten)]
        target: Target,
    },
}

#[derive(Subcommand)]
enum CoprocessorCommand {
    /// Show what a board's radio coprocessor has installed and is running
    Status(Target),

    /// Install one of ST's coprocessor images: a FUS update or a wireless stack. The coprocessor
    /// has to be running FUS, as it does on a new board. Without --board, installs on the only
    /// attached board that is in that state
    Install {
        /// The image, from STM32CubeWB's STM32WB_Copro_Wireless_Binaries
        image: PathBuf,

        #[command(flatten)]
        target: Target,
    },

    /// Remove the wireless stack, so that another can be installed
    Uninstall(Target),
}

/// Commands to interact with sensors
#[derive(Subcommand)]
enum SensorCommand {
    /// Read the current value of a sensor
    Read {
        /// Which sensor to read
        #[arg(long)]
        sensor: Sensor,

        #[command(flatten)]
        target: Target,
    },
    /// Measure temperature and relative humidity
    TempRh {
        /// How precisely to measure
        #[arg(long, default_value = "high", conflicts_with = "heat")]
        precision: Precision,

        /// Heat the sensor first, at this power, to drive off condensation. What is then measured,
        /// at high precision, is the heated sensor rather than the air
        #[arg(long, value_name = "POWER")]
        heat: Option<HeaterPower>,

        /// How long to heat the sensor for
        #[arg(
            long,
            value_name = "DURATION",
            default_value = "100ms",
            requires = "heat"
        )]
        heat_for: HeaterDuration,

        #[command(flatten)]
        target: Target,
    },
}

/// The board a command should target.
#[derive(Args)]
struct Target {
    /// The board's serial number, or the start of it. Only needed when several boards are attached
    #[arg(long, value_name = "SERIAL")]
    board: Option<String>,
}

impl Target {
    async fn board(&self) -> Result<Board> {
        Board::select(self.board.as_deref()).await
    }
}

/// The board that a `config` command applies to: an attached board, or a board that the attached
/// one reaches over its network.
#[derive(Args)]
struct ConfigTarget {
    /// The full serial number of a board on the attached board's network. The attached board
    /// relays the command to it
    #[arg(long, value_name = "SERIAL")]
    remote: Option<BoardId>,

    #[command(flatten)]
    attached: Target,
}

async fn list() -> Result<()> {
    let devices = board::devices().await?;
    if devices.is_empty() {
        bail!("no sensor board found on USB");
    }
    for device in &devices {
        // List a board even if it does not respond.
        match summary(device).await {
            Ok(summary) => println!("{}  {summary}", board::serial_of(device)),
            Err(e) => println!("{}  {e}", board::serial_of(device)),
        }
    }
    Ok(())
}

async fn summary(device: &nusb::DeviceInfo) -> Result<String> {
    let board = Board::open(device).await?;
    let info = board.info().await?;
    let status = board.network_status().await?;
    Ok(format!(
        "built {}  {}",
        info.firmware_built,
        network::describe(&status)
    ))
}

#[tokio::main]
async fn main() -> Result<()> {
    match Cli::parse().command {
        Command::List => list().await,
        Command::Network(NetworkCommand::Init {
            force_reinit,
            dataset_path,
        }) => {
            let path = match dataset_path {
                Some(path) => path,
                None => SavedDataset::default_path()?,
            };
            network::init(&Board::all().await?, &SavedDataset::at(path), force_reinit).await
        }
        Command::Network(NetworkCommand::Leave(target)) => target.board().await?.leave().await,
        Command::Network(NetworkCommand::Dataset(target)) => {
            let board = target.board().await?;
            match board.dataset().await? {
                Some(dataset) => println!("{dataset}"),
                None => bail!("board {} has no network", board.serial()),
            }
            Ok(())
        }
        Command::Network(NetworkCommand::Neighbors(target)) => {
            let board = target.board().await?;
            let table = board.neighbors().await?;
            if table.neighbors.is_empty() {
                println!("Board {} has no neighbors.", board.serial());
            } else {
                print!("{}", network::describe_neighbors(&table));
            }
            if let NetworkStatus::Configured(Link {
                role: Role::Child,
                rloc16,
                ..
            }) = board.network_status().await?
            {
                println!(
                    "The board is a child of router {:#06x}, which the table leaves out.",
                    RouterId::of_rloc16(rloc16).rloc16()
                );
            }
            Ok(())
        }
        Command::Network(NetworkCommand::Routers(target)) => {
            let board = target.board().await?;
            let table = board.routers().await?;
            if table.routers.is_empty() {
                println!("Board {} knows of no routers.", board.serial());
            } else {
                print!("{}", network::describe_routers(&table));
            }
            Ok(())
        }
        Command::Coprocessor(CoprocessorCommand::Status(target)) => {
            let board = target.board().await?;
            let status = board.coprocessor_status().await?;
            println!("{}  {}", board.serial(), coprocessor::describe(&status));
            Ok(())
        }
        Command::Coprocessor(CoprocessorCommand::Install { image, target }) => {
            let bytes = std::fs::read(&image)
                .with_context(|| format!("could not read {}", image.display()))?;
            coprocessor::install(target.board.as_deref(), &bytes).await
        }
        Command::Coprocessor(CoprocessorCommand::Uninstall(target)) => {
            coprocessor::uninstall(target.board().await?).await
        }
        Command::Bootloader(target) => {
            let board = target.board().await?;
            board.enter_bootloader().await?;
            println!("Board {} is rebooting into its bootloader.", board.serial());
            Ok(())
        }
        Command::Firmware(FirmwareCommand::Status(target)) => {
            let board = target.board().await?;
            let info = board.info().await?;
            let status = board.firmware_status().await?;
            println!(
                "{}  build {} (built {})  {}",
                board.serial(),
                status.build,
                info.firmware_built,
                firmware::describe(&status.update)
            );
            Ok(())
        }
        Command::Firmware(FirmwareCommand::Update { image, target }) => {
            let image = firmware::Image::read(&image)?;
            firmware::update(target.board().await?, &image).await
        }
        Command::Firmware(FirmwareCommand::Push { image, target }) => {
            let image = firmware::Image::read(&image)?;
            firmware::push(target.board().await?, &image).await
        }
        Command::Network(NetworkCommand::Addresses(target)) => {
            let board = target.board().await?;
            let addresses = board.addresses().await?;
            if addresses.addresses.is_empty() {
                println!("Board {} has no addresses.", board.serial());
            } else {
                print!("{}", network::describe_addresses(&addresses));
            }
            Ok(())
        }
        Command::Network(NetworkCommand::Show {
            border_router,
            target,
        }) => discovery::show(target.board.as_deref(), border_router.as_deref()).await,
        Command::Reports(ReportsCommand::Watch(target)) => {
            reports::watch(target.board.as_deref()).await
        }
        Command::Metrics(MetricsCommand::Show(target)) => {
            print!("{}", target.board().await?.metrics().await?);
            Ok(())
        }
        Command::Sensor(SensorCommand::Read { sensor, target }) => {
            let board = target.board().await?;
            let SensorValue { value } = board.read_sensor(sensor).await??;
            println!("Sensor value: {value}");
            Ok(())
        }
        Command::Config(ConfigCommand::Show(target)) => {
            let board = target.attached.board().await?;
            config::show(&board, target.remote).await
        }
        Command::Config(ConfigCommand::Set { changes, target }) => {
            let board = target.attached.board().await?;
            config::set(&board, target.remote, &changes).await
        }
        Command::Sensor(SensorCommand::TempRh {
            precision,
            heat,
            heat_for,
            target,
        }) => {
            let req = match heat {
                None => TempRhReq::Plain(precision),
                Some(power) => TempRhReq::Heated {
                    power,
                    duration: heat_for,
                },
            };
            let board = target.board().await?;
            let TempRh {
                temperature,
                humidity,
            } = board.measure_temp_rh(req).await??;
            println!("Temperature: {temperature:.2} °C");
            println!("Humidity: {humidity:.2} %RH");
            Ok(())
        }
    }
}

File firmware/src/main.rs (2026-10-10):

#![no_std]
#![no_main]

mod board_config;
mod coprocessor;
mod dfu;
mod discovery;
mod fault;
mod http;
mod i2c_device;
mod metrics;
mod persistent_config;
mod radio_flash;
mod report;
mod request;
mod rpc;
mod sensor;
mod thread;
mod update;
mod usb;

use defmt_rtt as _;
use embassy_executor::Spawner;

use embassy_stm32::{
    Config, Peri, bind_interrupts, dma,
    gpio::{self, Output},
    i2c,
    mode::Async,
    peripherals::{self, DMA1_CH1, DMA1_CH2, DMA2_CH1, I2C1},
    rcc,
    rtc::{Rtc, RtcConfig},
    wdg::IndependentWatchdog,
};
use embassy_sync::{blocking_mutex::raw::ThreadModeRawMutex, mutex::Mutex};
use embassy_time::{Duration, Timer};
use static_cell::StaticCell;

use crate::sensor::{
    capacitance::CapacitanceSensor,
    color::ColorSensor,
    mic::{
        Mic,
        pdm::{self, Pdm},
    },
    temp_rh::TempRhSensor,
};

bind_interrupts!(struct Irqs {
    I2C1_EV => i2c::EventInterruptHandler<I2C1>;
    I2C1_ER => i2c::ErrorInterruptHandler<I2C1>;
    DMA1_CHANNEL1 => dma::InterruptHandler<DMA1_CH1>;
    DMA2_CHANNEL1 => dma::InterruptHandler<DMA2_CH1>;
    DMA1_CHANNEL2 => dma::InterruptHandler<DMA1_CH2>;
});

fn configure_clocks() -> rcc::Config {
    let mut clocks = rcc::WPAN_DEFAULT;

    clocks.sys = rcc::Sysclk::HSE;
    clocks.hsi = true;
    clocks.core2_ahb_pre = rcc::AHBPrescaler::DIV1;

    // The PLL stays on only to give USB its 48 MHz from PLL Q. It is not the
    // system clock. USB cannot use HSI48, because CPU2 can switch that off.
    // TODO: disable this PLL and remove USB entirely so that we can go into
    // proper low-power sleep!
    clocks.hsi48 = None;
    clocks.mux.clk48sel = rcc::mux::Clk48sel::PLL1_Q;

    // The microphone (SAI1) wants a PDM clock of 2.048 MHz, which decimated by
    // 128 is 16 kHz audio. From 32 MHz that takes a /125 somewhere, and the
    // only place for it is the PLL input divider (shared by both PLLs) times
    // PLLSAI1's P: 32 / 5 = 6.4 MHz in, then 6.4 * 32 / 25 = 8.192 MHz for
    // SAI1, and 6.4 * 30 / 4 = 48 MHz for USB.
    clocks.pll = Some(rcc::Pll {
        source: rcc::PllSource::HSE,
        prediv: rcc::PllPreDiv::DIV5,
        mul: rcc::PllMul::MUL30,
        divp: None,
        divq: Some(rcc::PllQDiv::DIV4),
        divr: None,
    });
    clocks.pllsai1 = Some(rcc::Pll {
        source: rcc::PllSource::HSE,
        prediv: rcc::PllPreDiv::DIV5,
        mul: rcc::PllMul::MUL32,
        divp: Some(rcc::PllPDiv::DIV25),
        divq: None,
        divr: None,
    });
    clocks.mux.sai1sel = rcc::mux::Sai1sel::PLLSAI1_P;

    clocks
}

#[embassy_executor::task]
async fn coprocessor(task: coprocessor::Task<'static>) -> ! {
    task.run().await
}

#[embassy_executor::task]
async fn usb(mut device: usb::Device) -> ! {
    device.run().await
}

#[embassy_executor::task]
async fn rpc(mut server: rpc::Server) -> ! {
    loop {
        // `run` only returns with an error when the USB connection drops
        // (cable pulled, host reset the bus). Call it again so the server is
        // listening when the host reconnects.
        let _ = server.run().await;
    }
}

#[embassy_executor::task]
async fn bootloader(task: dfu::Task) -> ! {
    task.run().await
}

#[embassy_executor::task]
async fn reports(task: report::Task, publisher: rpc::Publisher) -> ! {
    task.run(publisher).await
}

#[embassy_executor::task]
async fn discovery(task: discovery::Task, publisher: rpc::Publisher) -> ! {
    task.run(publisher).await
}

#[embassy_executor::task]
async fn metrics(task: metrics::Task) -> ! {
    task.run().await
}

#[embassy_executor::task]
async fn watchdog(iwdg: Peri<'static, peripherals::IWDG>) -> ! {
    // 32 s because this chip pins the IWDG prescaler at /256 whatever is written, and that is the
    // period /256 expresses with the driver's reload maths (measurements in AGENTS.md).
    // TODO(aspen): verify that this is true
    let mut watchdog = IndependentWatchdog::new(iwdg, 32_000_000);
    watchdog.unleash();

    loop {
        Timer::after_millis(20).await;
        watchdog.pet();
    }
}

#[embassy_executor::task]
async fn blink(mut led: Output<'static>) {
    for _ in 0..=2 {
        led.set_low();
        Timer::after(Duration::from_millis(200)).await;
        led.set_high();
        Timer::after(Duration::from_millis(200)).await;
    }
}

#[embassy_executor::main]
async fn main(spawner: Spawner) {
    // Must run before any clock or peripheral setup.
    dfu::enter_bootloader_if_requested();
    dfu::reset_if_launched_by_bootloader();

    let mut config = Config::default();
    config.rcc = configure_clocks();
    let p = embassy_stm32::init(config);
    defmt::info!("sensor-board (built {})", env!("BUILD_STAMP"));

    // Option-validity error is set after FUS/bootloader activity; ST clears it
    // first thing in every WB application before any flash use.
    embassy_stm32::pac::FLASH
        .sr()
        .write(|w| w.set_optverr(true));

    let (_rtc, _rtc_time) = Rtc::new(p.RTC, RtcConfig::default());

    // let button = Input::new(p.PA7, Pull::Up); // SW1 to GND
    //

    spawner.spawn(watchdog(p.IWDG).unwrap());

    let (bootloader_task, bootloader_handle) = dfu::init();
    spawner.spawn(bootloader(bootloader_task).unwrap());

    let (update_handle, update_service) = update::init();
    let (config_handle, config_service, config_monitor) = board_config::init();
    let (coprocessor_task, coprocessor_handle, thread_handle, sockets, tcp) =
        coprocessor::Builder {
            ipcc: p.IPCC,
            flash: p.FLASH,
            update: update_service,
            board_config: config_service,
        }
        .init();
    spawner.spawn(coprocessor(coprocessor_task).unwrap());

    let (usb_device, link) = usb::Builder {
        usb: p.USB,
        dp: p.PA12,
        dm: p.PA11,
    }
    .init();
    spawner.spawn(usb(usb_device).unwrap());

    let scl = p.PB8;
    let sda = p.PB9;
    let mut config = i2c::Config::default();
    config.timeout = Duration::from_millis(10);

    static I2C: StaticCell<Mutex<ThreadModeRawMutex, i2c::I2c<'static, Async, i2c::Master>>> =
        StaticCell::new();
    let i2c = I2C.init(Mutex::new(i2c::I2c::new(
        p.I2C1, scl, sda, p.DMA1_CH1, p.DMA2_CH1, Irqs, config,
    )));

    static CAPACITANCE: StaticCell<sensor::Shared<CapacitanceSensor<'static>>> = StaticCell::new();
    let capacitance = &*CAPACITANCE.init(Mutex::new(CapacitanceSensor::new(p.PB4, i2c)));

    static COLOR: StaticCell<sensor::Shared<ColorSensor<'static>>> = StaticCell::new();
    let color = match ColorSensor::init(i2c).await {
        Ok(sensor) => Some(&*COLOR.init(Mutex::new(sensor))),
        Err(e) => {
            defmt::warn!("color sensor failed to initialize: {}", e);
            None
        }
    };
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

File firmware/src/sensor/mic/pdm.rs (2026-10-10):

//! SAI1's PDM interface (RM0434 39.4.10), for one PDM microphone.
//!
//! The PDM interface takes the clock of sub-block A, which runs as a master
//! receiver in TDM, and hands sub-block A the bitstreams of up to two pairs
//! of microphones (data lines D1 and D2 on this chip) de-interleaved into
//! bytes: a frame has an 8-bit slot for each microphone, the left one of a
//! pair first, and the bitstream clock is SCK_A / (2 * pairs). Only the slot
//! of the microphone asked for is captured, so every byte DMA delivers is
//! eight of its samples, the first in the MSB.

use embassy_stm32::{
    Peri,
    dma::{self, ReadableRingBuffer, TransferOptions},
    gpio::{self, AfType, Flex, OutputType, Pull, Speed},
    interrupt,
    pac::{self, sai::vals},
    peripherals::{PA3, PA8, PA9, PA10, PB8, PB9, SAI1},
    rcc,
    sai::{self, Dma},
};

/// The bitstream clock: 16 kHz decimated by 128.
pub const CLOCK_HZ: u32 = 2_048_000;

/// The PDM signals are alternate function 3 wherever they are.
const AF: u8 = 3;

mod sealed {
    pub trait Sealed {}
}

/// A pin that can carry a bitstream clock, SAI1_CK1 or SAI1_CK2.
pub trait ClockPin: gpio::Pin + sealed::Sealed {
    /// Which of the `CKEN` bits enables it.
    const CKEN: usize;
}

/// A pin that can carry the data of a pair of microphones, SAI1_D1 or
/// SAI1_D2.
pub trait DataPin: gpio::Pin + sealed::Sealed {
    /// Which pair's data it carries, from 0.
    const PAIR: u8;
}

macro_rules! clock_pins {
    ($($pin:ident: $cken:literal),+) => {$(
        impl sealed::Sealed for $pin {}
        impl ClockPin for $pin {
            const CKEN: usize = $cken;
        }
    )+};
}

macro_rules! data_pins {
    ($($pin:ident: $pair:literal),+) => {$(
        impl sealed::Sealed for $pin {}
        impl DataPin for $pin {
            const PAIR: u8 = $pair;
        }
    )+};
}

clock_pins!(PA3: 0, PB8: 0, PA8: 1);
data_pins!(PA10: 0, PA9: 1, PB9: 1);

/// Which microphone of the pair on a data line: the one whose data is valid
/// on the rising edge of the clock, or the falling one. The microphone's L/R
/// pin chooses (RM0434 figure 396).
#[derive(Debug, Clone, Copy, defmt::Format)]
pub enum Channel {
    /// L/R tied to VDD.
    #[expect(dead_code, reason = "no board has its microphone strapped left")]
    Left,
    /// L/R tied to GND, or floating if the microphone pulls it down.
    Right,
}

/// DMA overwrote part of the bitstream before it was read.
#[derive(Debug, defmt::Format)]
pub struct Overrun;

pub struct Pdm<'d> {
    _sai: Peri<'d, SAI1>,
    _clock: Flex<'d>,
    _data: Flex<'d>,
    ring: ReadableRingBuffer<'d, u8>,
    mckdiv: vals::Mckdiv,
    /// MICNBR: the pairs of microphones, less one.
    micnbr: u8,
    cken: usize,
    slot: usize,
    running: bool,
}

impl<'d> Pdm<'d> {
    /// Sets the pins and DMA up, and leaves the interface off: `start` turns
    /// it on.
    ///
    /// Panics unless SAI1's kernel clock divides down to `CLOCK_HZ`.
    pub fn new<C: ClockPin, D: DataPin, Ch: Dma<SAI1, sai::A>>(
        sai: Peri<'d, SAI1>,
        clock: Peri<'d, C>,
        data: Peri<'d, D>,
        channel: Channel,
        dma: Peri<'d, Ch>,
        irq: impl interrupt::typelevel::Binding<Ch::Interrupt, dma::InterruptHandler<Ch>> + 'd,
        buf: &'d mut [u8],
    ) -> Self {
        let micnbr = D::PAIR;
        let sck_hz = CLOCK_HZ * 2 * (micnbr as u32 + 1);
        let kernel_hz = rcc::frequency::<SAI1>().0;
        let mckdiv = kernel_hz / sck_hz;
        assert!(
            kernel_hz % sck_hz == 0 && (1..64).contains(&mckdiv),
            "SAI1's kernel clock ({} Hz) does not divide down to {} Hz",
            kernel_hz,
            sck_hz
        );

        let mut clock = Flex::new(clock);
        clock.set_as_af_unchecked(AF, AfType::output(OutputType::PushPull, Speed::High));
        let mut data = Flex::new(data);
        data.set_as_af_unchecked(AF, AfType::input(Pull::None));

        let request = dma.request();
        // SAFETY: the data register of block A, which this owns through
        // `sai`, read in bytes as `DS` makes them.
        let ring = unsafe {
            ReadableRingBuffer::new(
                dma::Channel::new(dma, irq),
                request,
                pac::SAI1.ch(0).dr().as_ptr() as *mut u8,
                buf,
                TransferOptions::default(),
            )
        };

        Self {
            _sai: sai,
            _clock: clock,
            _data: data,
            ring,
            mckdiv: vals::Mckdiv::from_bits(mckdiv as u8),
            micnbr,
            cken: C::CKEN,
            slot: 2 * micnbr as usize + channel as usize,
            running: false,
        }
    }

    /// Clocks the microphone and starts taking its bitstream in. The
    /// microphone takes up to 10 ms to give valid data.
    pub fn start(&mut self) {
        rcc::enable_and_reset::<SAI1>();

        let sai = pac::SAI1;
        let a = sai.ch(0);
        let slots = 2 * (self.micnbr + 1);
        // RM0434 table 246, for 8-bit slots.
        a.cr1().modify(|w| {
            w.set_mode(vals::Mode::MASTER_RX);
            w.set_ds(vals::Ds::BIT8);
            w.set_nodiv(true);
            w.set_mckdiv(self.mckdiv);
            w.set_dmaen(true);
        });
        a.frcr().modify(|w| {
            w.set_frl(8 * slots - 1);
            // The frame sync is internal, but the PDM interface goes by it:
            // at reset (0) every byte is scrambled.
            w.set_fspol(vals::Fspol::RISING_EDGE);
        });
        a.slotr().modify(|w| {
            w.set_nbslot(slots - 1);
            w.set_sloten(vals::Sloten::from_bits(1 << self.slot));
        });
        sai.pdmcr().modify(|w| {
            w.set_micnbr(self.micnbr);
            w.set_cken(self.cken, true);
            w.set_pdmen(true);
        });

        self.ring.clear();
        self.ring.start();
        a.cr1().modify(|w| w.set_saien(true));
        self.running = true;
    }

    /// Stops the clock, which puts the microphone in power-down, and turns
    /// SAI1 off.
    pub fn stop(&mut self) {
        let a = pac::SAI1.ch(0);
        a.cr1().modify(|w| w.set_saien(false));
        // SAIEN reads back as set until the frame under way has ended.
        while a.cr1().read().saien() {}
        pac::SAI1.pdmcr().modify(|w| w.set_pdmen(false));

        self.ring.request_pause();
        while self.ring.is_running() {}
        rcc::disable::<SAI1>();
        self.running = false;
    }

    /// Fills `buf` with the bitstream that follows what was last read, eight
    /// samples to a byte, the first in the MSB. After an overrun the next
    /// read starts from what arrives then.
    pub async fn read(&mut self, buf: &mut [u8]) -> Result<(), Overrun> {
        if self.ring.read_exact(buf).await.is_err() {
            self.ring.clear();
            return Err(Overrun);
        }
        Ok(())
    }
}
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

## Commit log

2026-08-27 Start CAD for the sensor board
    Power, clock, antenna, water sensor, color sensor, and distance sensor
    heavily based on dan foisy's board, but has already diverged somewhat in
    using USB C instead of micro B, and will diverge more (we're gonna have,
    eg, capacitive soil sensors)
    [sensor-board.kicad_pcb, sensor-board.kicad_sch]
2026-08-29 more or less final schematic; on to layout
    [sensor-board.kicad_sch]
2026-08-29 mostly footprint assignment, only not battery
    [sensor-board.kicad_pcb, sensor-board.kicad_sch]
2026-08-30 edit stackup & net classes
    [sensor-board.kicad_pcb]
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2026-08-30 Some board grouping, no traces yet
    [sensor-board.kicad_pcb, sensor-board.kicad_sch]
2026-08-30 Starting a little bit of routing; starting with HF crystal
    [sensor-board.kicad_pcb, sensor-board.kicad_sch]
2026-08-31 SMPS and (most of) LF crystal
    [sensor-board.kicad_pcb, sensor-board.kicad_sch]
2026-08-31 finish off LF crystal (except for GND connection)
    [sensor-board.kicad_pcb]
2026-09-01 ~Finished routing, not yet DRC-clean
    [sensor-board.kicad_pcb, sensor-board.kicad_sch]
2026-09-03 Address some human-discovered issues
    [sensor-board.kicad_pcb, sensor-board.kicad_sch]
2026-09-04 Fix all of claude's issues
    [sensor-board.kicad_pcb]
2026-09-06 jlcpcb (rotated wrong)
    [BOM-sensor-board.csv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]
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2026-10-04 Talk to boards over postcard-rpc, with a CLI to set them up
    The firmware is now a USB device that serves typed endpoints, defined in
    protocol/, in place of the text console. cli/ (sensor-board-cli) calls
    them: it lists boards, puts them on one Thread network whose dataset it
    keeps between runs, installs and removes CPU2 firmware through FUS, and
    reboots a board into its ROM bootloader.
    In the firmware a coprocessor task owns CPU2 and runs either Thread or
    the FUS installer, depending on what it finds there. Handles reach both
    through requests with a bounded wait, and the state a task shares with
    its handles is made in the init that returns them. CPU2 is only ever
    pointed at memory that it r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
    [lib.rs, main.rs, mod.rs]
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2026-10-04 Add command to read the router table
    `network routers` lists every router on a board's network with what the
    board's Thread stack does to reach it: directly, or through which other
    router, and at what path cost.
    Also corrects what the neighbor table is said to hold: a child's parent
    is not in it, and `network neighbors` now says so for a child.
    [lib.rs, main.rs, mod.rs]
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2026-10-04 Send sensor reports over the mesh, and collect them through a board
    Every board broadcasts a `Report` of its readings over UDP every ten
    seconds. A board that the host tells to collect takes in the reports that
    arrive, its own among them, and passes them on over USB as a postcard-rpc
    topic. `sensor-board-cli reports watch` prints them, and `reports export`
    serves them to Prometheus.
    The Thread service now takes requests and CPU2's notifications in one
    loop, and acknowledges a notification only once it has dealt with it: a
    received datagram has to be read before that. This needs
    `ThreadNotifRx::receive_with`, so the embassy fork is pinned at the
    revision that adds it. The bindings are regene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
    [lib.rs, main.rs, mod.rs]
2026-10-04 Update the firmware through the firmware, behind a bootloader
    Flash below CPU2's stack is now shared out between a bootloader
    (embassy-boot), the firmware, and a staging area for a firmware update;
    the stored configuration keeps its page between the two. The firmware
    takes an image into the staging area, checks its SHA-256, and has the
    bootloader swap it in at the next reset. The update then runs on trial:
    it is kept once the board is back on its network, and a reset before
    that, or five minutes without the network, brings the old firmware back.
    `sensor-board-cli firmware update` sends an image over USB, and
    `firmware status` says which build runs and where an update stands. The
    Justfile fl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
    [firmware.rs, lib.rs, main.rs]
2026-10-04 Update the firmware of every board over the mesh, through one on USB
    A board that has an image staged can now offer it to the boards on its
    network, once the host tells it to. Every board listens on a second UDP
    port for that. One that runs another build asks the offering board for
    the image 192 bytes at a time, stages it, checks it, and restarts into
    it, on trial as with an update over USB. A board whose trial of a build
    failed finds that build in its staging area and does not fetch it again.
    `sensor-board-cli firmware push` sends the image to the attached board,
    has it offer the image, and follows the boards' reports until every one
    it hears from runs the build; the attached board goes la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
    [firmware.rs, lib.rs, main.rs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]
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2026-10-08 Serve the reports' metrics with metrics-exporter-prometheus
    In place of the HTTP server and the text format written by hand. The
    metrics and their labels are the same. What differs:
    - A board that has gone quiet for a minute loses all its gauges, the time
    of its last report and its firmware build among them. Its counters stay.
    - A reading that fails leaves the channel's last value until that goes
    stale, rather than taking it away at once.
    - A gauge is stale once two scrapes at least a minute apart find it the
    same.
    - Any path is answered with the metrics, and /health with OK.
    Of the exporter's features only the HTTP listener is built: the default
    ones add a push gateway and a TLS sta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
2026-10-10 Have boards get their metrics to Prometheus themselves
    A board on aux power serves its metrics at /metrics on TCP port 9469. A
    board on battery pushes them to the Pushgateway in its configuration each
    time it has read a sensor, and leaves a gateway that did not take a push
    alone for a minute. The sensors are read at the intervals the configuration
    gives them, and the metrics are tinymetrics'.
    TCP is the stack's own, on CPU2: the Thread service has one endpoint of it,
    and so one connection at a time. The bindings are regenerated for its types.
    The configuration gains the Pushgateway's address, which changes its
    layout: a board has no configuration until it is given one again.
    `metrics show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
    [lib.rs, main.rs]
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2026-10-10 Reword log, error and metric help messages
    Use plainer wording for the messages added with the board configuration
    (25fe8ad) and the Prometheus export (7708444): the firmware's log lines,
    the HELP text of its metrics, and the CLI's errors for `config`.
    Metric names, labels and types are unchanged.
    [lib.rs, mod.rs]
2026-10-10 Rename identifiers and tests to plainer names
    Use the usual terms for private functions, types, locals and tests:
    - request channel: `ask`/`answer` become `call`/`respond`
    - services: `answer`, `heard`, `tell`, `keep`, `tick` become
    `handle_request`, `handle_datagram`, `reply`, `store`, `handle_timers`
    - board config: `Asking` becomes `Forwarded`, `ask`/`ask_again` become
    `forward`/`resend`
    - updates: `Arriving` becomes `Incoming`, `FetcherHeard` becomes
    `TrackedFetcher`, `offered`/`got_chunk`/`asked_for_chunk` become
    `handle_offer`/`handle_chunk`/`handle_chunk_request`
    - metrics: `Recorded::start_afresh` becomes `SharedMetrics::reset`,
    `OfBoard`/`OfChannel` become `BoardLabels`/`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
    [firmware.rs, lib.rs]
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2026-10-11 Record two boards that stopped using the radio
    Two boards stopped receiving and sending on 2026-10-11, one and five
    minutes after they had restarted into an image fetched from the CLI
    through the border router. CPU2 still answered calls and CPU1 kept
    running, so nothing reset them. The cause is not known, and it did not
    happen again on a restarted board. AGENTS.md now describes what was
    seen, so that it can be recognized.
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2026-10-11 Make boards on battery sleepy end devices
    A board whose power mode is battery turns its receiver off. It is a
    synchronized sleepy end device if the shortest poll interval of its
    sensors fits in a CSL period (about 10.5 s), and otherwise polls its
    parent at that interval. It polls fast while it has a TCP connection and
    for two seconds after it sends a datagram, so that the answers reach it.
    It lets its radio enter low power, and it no longer sends sensor reports.
    The Thread service takes the mode from the board's configuration: before
    the board first attaches, and again when the configuration changes.
    Add the network mode command, which shows the mode a board is in.
    Only the radio sleeps.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
2026-10-12 Note two power changes for rev 2
    Add a VBUS sense pin, and replace JP2 with a power path that keeps USB
    power off the 3 V rail.
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2026-10-12 Drop the synchronized sleepy mode
    A board on battery now always polls its parent every ten seconds. With a
    CSL period of 10 s, messages to a silent board had gaps of 30 to 60 s,
    and polling delivered every ping within 11 s.
    Remove what only the synchronized mode used: the CSL period and child
    timeout calls, and the shortest sensor interval.
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2026-10-12 Wait for boards on battery in network show, and document them
    Through the border router, network show now waits a poll period for the
    boards that mDNS advertises as on battery. It stopped listening after
    three seconds before, and usually missed them.
    Rewrite the section on boards on battery in AGENTS.md and in the README
    for what the branch now does: no USB, the button, the sleepy end device,
    how such a board is reached and found, and what was tested.
    Tested on boards: just push with no board attached updated two boards on
    aux power and one on battery that was off USB, and network show through
    the border router listed all three.
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2026-10-12 Document Stop mode on boards on battery
    What the patch to embassy-stm32 fixes, why a board that a probe has touched
    does not stop, what was tested on a board, and what is left: the current
    has not been measured, and the button has not been tried on a board that
    stops.
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2026-10-12 Correct the measured current, and record the flash-write hang
    The current of a stopped board is 0.02 mA, not 0.002.
    A board that really stops hangs when it writes its flash: a config set
    through the border router got no reply and left the old configuration, the
    button did not erase it, and each time the watchdog reset the board about
    30 s later. Not solved yet.
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2026-10-18 Retry the scrape endpoint registration until it succeeds
    The scrape endpoint registered once at start, and again only after a
    scrape. If the first attempt failed, the board stayed unregistered:
    Prometheus finds boards over mDNS, so nothing scraped it. Now a board
    that is not registered waits for a scrape for 5 s at a time, and
    registers again in between, as a board that pushes already does.
    Claude-Session: https://claude.ai/code/session_01GH9yfQyU1do5HNkhQ4fMve
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2026-10-18 Report the capacitance sensor's readings in picofarads
    The board has an FDC2114, not the FDC2214 that the driver was written
    for. The driver read a DATA_LSB register that the FDC2114 does not have,
    and left the clock dividers at their reserved reset value, so its raw
    readings had no defined scale.
    The driver now configures every channel for the board's single-ended
    18 uH / 33 pF tanks and the internal oscillator, and keeps the chip
    asleep between readings. A reading converts the measured frequency to
    the capacitance on the electrode, in pF. The protocol carries it as
    `Capacitance`, in the reports and through the new `ReadCapacitance`
    endpoint, which replaces `ReadSensorValue`. The metrics e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
2026-10-18 Drive the capacitance sensor as the FDC2214 that's on the boards
    The schematic says the chip is an FDC2114, but U9 on the boards is an
    FDC2214. It answers with device ID 0x3055 and gives a 28-bit result. The
    previous commit checked for the FDC2114's ID, so the sensor never
    initialized and every reading failed.
    Go back to the FDC2214 register map, read both DATA and DATA_LSB, and
    convert the 28-bit result. Report the chip's under-range and over-range
    results as OutOfRange, and change that error's message so it no longer
    mentions the color sensor. Make each conversion 65536 reference clock
    cycles long, which gives about 16 effective bits.
    Also reword the comments and docs from the previous c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
2026-10-18 Reword the writing-style rule in AGENTS.md
    Asking for short sentences led to squeezed wording, like "the boards
    carry an FDC2214" instead of "the FDC2214 that's on the boards". Ask for
    writing that sounds like how you would say it to a colleague, and give
    examples of the everyday wording to use.
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2026-10-18 Take embassy-stm32 from the fork instead of patching it
    The Stop-mode fixes are now on the wb55-stop branch of
    github.com/glittershark/embassy, which starts from the 0.6.0 release.
    firmware/Cargo.toml points [patch.crates-io] at that branch, so the
    patch file and the just recipe that unpacked and patched the crate are
    gone, and cargo works in a fresh checkout without running it first.
2026-10-18 Use fixed-point gauges for the sensor readings
    tinymetrics' `Gauge` holds an f64, and the code that formats an f64 for
    the metrics text took about 10 K of flash. Use Aspen's fork of
    tinymetrics, which adds `FixedGauge`, a gauge that holds a fixed-point
    number from the `fixed` crate and formats it with integer arithmetic.
    Temperature, humidity and sound level use I16F16, and capacitance in
    farads uses I14F50.
    This takes the image from 227,780 to 218,924 bytes. The values in the
    metrics text now have as many decimal places as the type's resolution
    allows, for example 24.65286 instead of 24.652854919433594.
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2026-10-19 Remove the sensor reports
    The metrics have replaced what the reports were for. The only thing still
    using them was `firmware push`, which read the build each board runs from
    them. Every board now replies to an update offer with its build instead
    (`UpdateMessage::Running`, added at the end of the enum). The offering
    board keeps the builds it hears about, and the CLI reads them with the new
    `GetRunningBuilds` endpoint. This also shows the build of a board on
    battery, which never sent reports.
    Remove the report task and its socket, the collect endpoints, the
    `ReportReceived` topic, the types that only the reports used, and
    `reports watch`. Boards no longer read every sensor every ten seconds f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
2026-10-24 Shorten the motion sensor's hold to 20 s
    A detection now ends once the sensor has seen nothing for 20 s instead
    of a minute, so Home Assistant learns sooner that a room is empty. The
    hold still bridges the gaps between someone's movements, during which
    the sensor's output is low. After a restart, the board reports "no
    motion" after 20 s without any.
2026-10-24 Note that reading the chip over SWD triggers the motion sensor
    With the sensor covered and probe-rs reading PA2 every half second, the
    sensor's output went high every second or two, and it went quiet once
    the reads stopped. Its datasheet asks for a capacitor at its power pin,
    which the board doesn't have, so add that to the list for rev. 2.
2026-10-24 Add the STM32WB55 errata sheet
    ES0394, Rev 17 (October 2025), the device errata for the STM32WB55 and
    STM32WB35, next to the chip's datasheet and reference manual.
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2026-10-25 Take embassy-stm32 with the fix for lost EXTI edges in Stop mode
    After every stop, embassy's time driver cleared the RTC's line in EXTI's
    pending register with a read-modify-write. The register is
    write-1-to-clear, so that cleared every pending line, including the one
    for the edge that had woken the chip. On a board on battery the motion
    sensor's detections then didn't start, or never ended. The fix is on the
    fork's wb55-stop branch.
2026-10-25 Note that erratum 2.2.21 applies to the boards' chips
    ES0394 says the SMPS can make the system unstable when it switches to
    bypass in Stop 1 or Stop 2, and that's how a board on battery runs. It
    applies to silicon revision Y, which board 4D0021 has.
2026-10-26 Retry a failed report after 5 s, and count failures by cause
    After hours without an exchange, a board's first report to Home
    Assistant sometimes fails, and the next one a few seconds later
    succeeds. Its retry used to wait a minute, so Home Assistant learned of
    the motion a minute late. Now the first retry comes after 5 s, and the
    later ones after a minute, as before.
    The metrics now count failed reports and pushes by why they failed, in
    an `error` label, so that a board on battery shows the cause without a
    probe.
2026-10-26 Abort a leftover TCP connection instead of refusing to connect
    The Thread service sometimes still had a connection recorded when the
    next exchange began, although the last one had ended with Tcp::close.
    It then refused the connect as out of sequence, which failed the first
    report to Home Assistant after hours of quiet on board 4D0021. A
    connect now aborts the leftover connection first, as an accept already
    does with a connection that never opened.
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2026-10-27 Bring the list of embassy bugs to send upstream up to date
    Adds the exti fix from 2026-10-25, and a part for embassy-stm32-wpan:
    the Thread subsystem and the rest of wb55-thread, the fix for Bluetooth
    events that stalled after one or two, and the fields that
    ShciBleInitCmdParam lacks for stack v1.24.
2026-10-27 Remove board-to-board update offers and the sensor commands
    Both took flash for something the CLI can do without them, and the
    firmware is 8.3 K smaller: 203,704 bytes instead of 212,016. That fits
    the 200 K that a board with ST's stack for Bluetooth and Thread leaves
    for the firmware, if the bootloader's region shrinks to 8 K.
    An attached board no longer offers its staged image to the others, so
    `firmware push` always goes through the border router, as it did with
    no board attached. What the attached board told the CLI, the CLI now
    learns itself: every board replies to each offer with the build it
    runs, and the CLI used to ignore those replies. It now prints the build
    of each board, counts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
2026-10-28 Report whether the supply is low at rest, not whether it ever dipped
    The metric latched the first time the supply detector tripped, and a
    coin cell sags below 2.64 V while the radio transmits: on boards 4D0021
    and 4B002E it tripped within ten minutes of every start, also on a fresh
    cell, and the alert in Grafana repeated every day. The metric now shows
    the detector's output when the metrics are rendered, before a push with
    the board idle, which says whether the cell itself is low. The
    interrupt is no longer needed.
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2026-11-01 Raise the limit for an HTTP body from 4 K to 6 K
    The help and type lines of the metrics alone take about 3.5 K of a
    scrape, and a text that doesn't fit fails the whole scrape with a 500.
    Board 4C0045, with two capacitance channels, temperature and humidity,
    answered every scrape that way on 2026-11-01, after 00be1f3 added
    sensor_board_late_tcp_events_total. The larger buffers take about 4 K
    more RAM.
2026-11-01 Read the supply only while the radio is quiet
    The metric read the supply detector when the metrics were rendered, and
    on board 4D0021 that comes right after its report to Home Assistant,
    while a coin cell is still recovering from the radio's burst. It read
    low on a cell that measured 2.91 V on a meter (2026-10-31).
    A supply task now reads the detector 5 s after the board's last exchange
    over the radio, which the Thread service publishes, and at most every
    30 s. The supply counts as low once every reading for 10 minutes has
    been low, so a cell that recovers between bursts doesn't.
2026-11-01 Let an offer replace a fetch that has given up
    A board that was fetching an image whose host stopped answering kept
    that image as the one being received, and ignored every offer of
    another image until it restarted. After a push that was stopped
    partway on 2026-11-01, boards 4B002E and 4D0021 ignored the next push,
    and the CLI said the image had failed on them before or didn't fit. A
    fetch that has given up now gives way to an offer of another image. A
    fetch that is still going, and an image from the host over USB, still
    don't.
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2026-11-01 Keep finding the boards during a push when one way of looking fails
    A push through the border router looks the boards up again every 30 s,
    because a board that restarts into the image gets a new address. The
    look-up asked the border router and then mDNS, and dropped what mDNS
    found when the border router failed, silently. The boards on battery are
    only on mDNS. On 2026-11-01 a push heard none of three boards come back
    on their new addresses, although they did, within a minute.
    The two are now looked up separately, and each refresh prints what
    failed and how many addresses it added. avahi-browse, which sometimes
    hangs for minutes, has 20 s and is then killed, so that one hang can't
    hold up t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
2026-11-07 button-board: first crack at layout
2026-11-08 Restart the board when CPU2 doesn't answer a call
    On 2026-11-08, board 4D0021 had been waiting 12 hours for CPU2 to answer
    an otTcpAbort. The OT command channel stayed occupied, nothing was
    waiting for CPU1 to acknowledge, and CPU2 never went into deep sleep.
    The Thread service handles one request at a time, so every push and
    every report to Home Assistant timed out. The board dropped out of its
    parent's child table and its registration ran out, but CPU1 kept
    feeding the watchdog.
    A call that CPU2 doesn't answer within 30 s now resets the system,
    which also restarts CPU2. The reset counts as a failed boot. AGENTS.md
    describes the hang and how to read it over the probe without halting
    the ch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
2026-11-09 Make the calls that read a received datagram without a timeout
    5b5fb0f put a 30 s timeout around every call to CPU2, including the
    ones that read a received UDP datagram. Those run under `block_on`,
    outside the executor, and an embassy timer polled there panics. So every
    datagram that a board received restarted it. On 2026-11-08 a push of
    5b5fb0f took all four boards off the network: the offers that came
    every 10 s gave each one three failed boots in a row, and put it in the
    ROM bootloader.
    The calls under `block_on` now go through `Blocking`, which has no
    timeout. If CPU2 hangs during one of them, no task runs, so the
    watchdog resets the chip.
    Tested on 4C0045, flashed over SWD: it answer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
2026-11-09 Keep a bad update from taking boards off the network
    Three changes, so that a build like 5b5fb0f rolls itself back instead of
    putting every board in the ROM bootloader:
    - An update is only kept once the board is back on its network, has
    received a datagram, and has run for three minutes. It used to be kept
    a few seconds after the start. A board on trial sends itself a
    datagram every 30 s until one arrives, so the trial doesn't depend on
    a host. It receives offers during the trial, but answers them only
    after it.
    - After three failed boots in a row, a board goes back to the firmware
    from before its last update, if the staging area still holds it. It
    writes the state page so tha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
2026-11-09 button-board: cleaning up issues pre-fabrication
